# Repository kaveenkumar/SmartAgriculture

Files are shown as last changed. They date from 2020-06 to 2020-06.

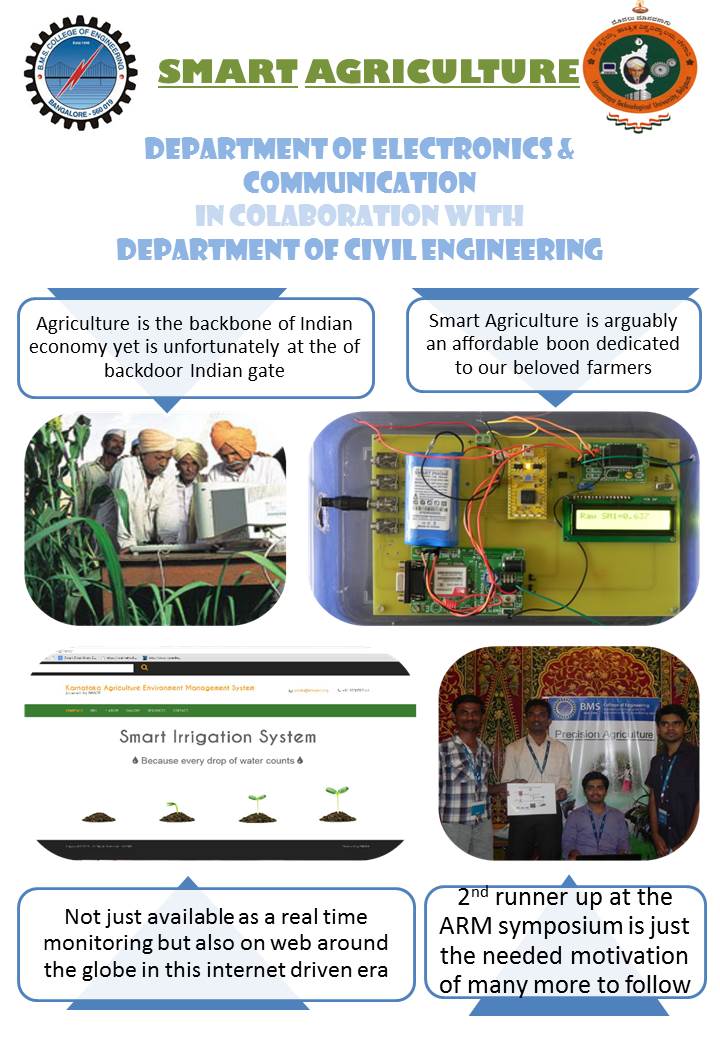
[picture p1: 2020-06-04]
Posters/SA Poster/Smart Agriculture poster.jpg

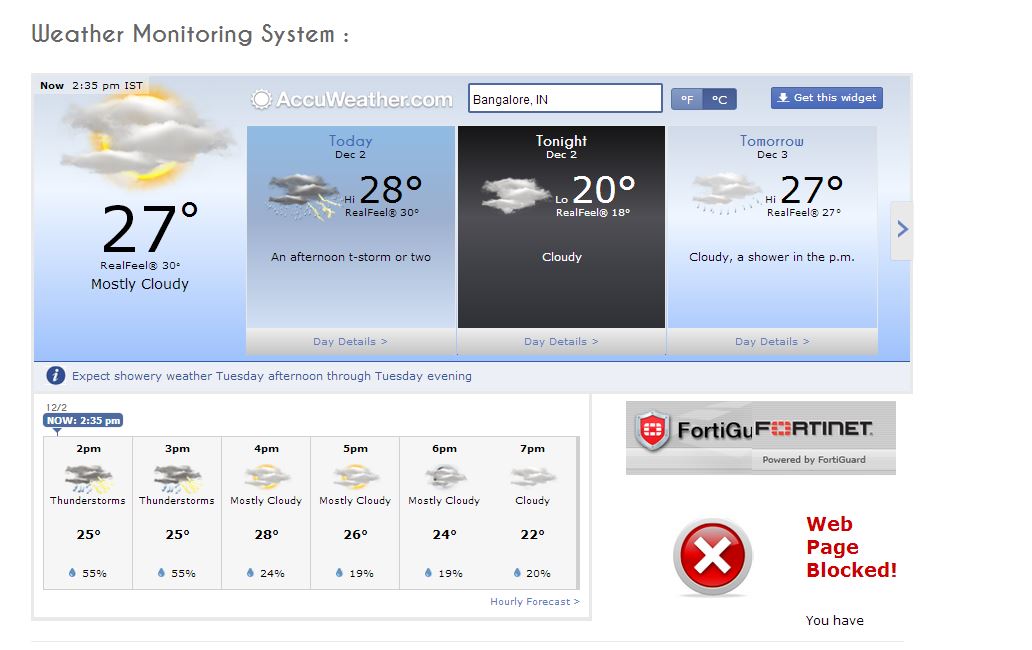
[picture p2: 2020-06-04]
Images/6.JPG

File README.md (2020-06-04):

# SmartAgriculture
Bachelor’s final year project, 2014.

## Control of waterflow to irrigation lands from a central system using wireless communication.
Currently deployed at the institute, BMS College of Engineering, Bangalore

### Reference
https://www.researchgate.net/project/Smart-Agriculture-13

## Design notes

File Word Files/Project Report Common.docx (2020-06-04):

B.M.S COLLEGE OF ENGINEERING

(Autonomous College under VTU)

Department of Electronics and Communication Engineering

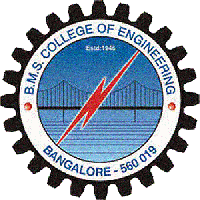
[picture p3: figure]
495086587logo%20bms

CERTIFICATE

This is to certify that the project entitled “PRECISION AGRICULTURE” is a bonafide work carried out by Hemantha Gowda C V (USN:1BM11EC406), Kaveen Kumar M K (USN:1BM11EC408), Nikhil D G (USN:1BM11EC415) and Prathap J (USN:1BM11EC417) in partial fulfillment for the award of Bachelor of Engineering degree by VTU Belgaum, during the academic year 2013-2014.

Harish V Mekali Dr.D .Seshachalam Dr.K.Mallikharjuna Babu

Assistant Prof., ECE, BMSCE HOD, ECE, BMSCE Principal, BMSCE

External Examination: Signature with date:

1.

2.

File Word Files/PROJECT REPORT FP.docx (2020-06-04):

PROJECT REPORT

ON

“PRECISION AGRICULTURE”

Submitted in partial fulfilment of the requirements for the award of degree of

BACHELOR OF ENGINEERING

IN

ELECTRONICS AND COMMUNICATION ENGINEERING

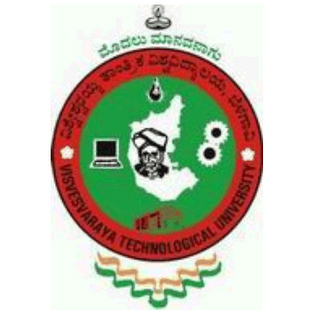
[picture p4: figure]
vtu_logo_gif

VISVESVARAYA TECHNOLOGICAL UNIVERSITY, BELGAUM

SUBMITTED BY:

HemanthaGowda C V 1BM11EC406

Kaveen Kumar M K 1BM11EC408

Nikhil D G 1BM11EC415

Prathap J 1BM11EC417

Under the Guidance of

Harish V Mekali

(Assistant Professor, ECE, BMSCE)

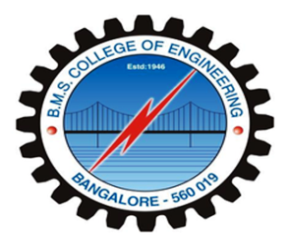
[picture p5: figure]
BMS LOGO

Department of Electronics and Communication Engineering

B.M.S COLLEGE OF ENGINEERING

(Autonomous College Affiliated to Visvesvaraya Technological University, Belgaum)

Bull Temple Road, Basavanagudi, Bangalore-560019

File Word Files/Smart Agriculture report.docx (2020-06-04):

PROJECT REPORT

ON

“SMART AGRICULTURE”

Submitted in partial fulfilment of the requirements for the award of degree of

BACHELOR OF ENGINEERING

IN

ELECTRONICS AND COMMUNICATION ENGINEERING

VISVESVARAYA TECHNOLOGICAL UNIVERSITY, BELGAUM

SUBMITTED BY:

Hemantha Gowda C V 1BM11EC406

Kaveen Kumar M K 1BM11EC408

Nikhil D G 1BM11EC415

Prathap J 1BM11EC417

Under the Guidance of

Harish V Mekali

(Assistant Professor, ECE, BMSCE)

Department of Electronics and Communication Engineering

B.M.S COLLEGE OF ENGINEERING

(Autonomous College Affiliated to Visvesvaraya Technological University, Belgaum)

Bull Temple Road, Basavanagudi, Bangalore-560019

B.M.S COLLEGE OF ENGINEERING

(Autonomous College under VTU)

Department of Electronics and Communication Engineering

CERTIFICATE

This is to certify that the project entitled “SMART AGRICULTURE” is a bonafide work carried out by Hemantha Gowda C V(USN:1BM11EC406), Kaveen Kumar M K (USN:1BM11EC408),Nikhil D G(USN:1BM11EC415) and Prathap J (USN:1BM11EC417) in partial fulfillment for the award of Bachelor of Engineering degree by VTU Belgaum, during the academic year 2013-2014.

Harish V Mekali Dr.D .Seshachalam Dr.K.Mallikharjuna Babu

Assistant Prof., ECE, BMSCE HOD, ECE, BMSCE Principal, BMSCE

External Examination: Signature with date:

1.

2.

This work is dedicated to all the farmers of the nation

ABSTRACT

Our planet is progressively marching towards a serious electric energy crisis, owing to an escalating desire of electric energy becoming greater than its supply. We have always failed to accept that the energy we make use of each day is restricted, yet taking it for granted. Coal, petroleum, electric power, even water has inadequate availability. Nevertheless, we have not taken sufficient precautions to handle a possible energy crisis. Another main concern has been the lifespan of guided media and its loopholes to intercept and eavesdrop.

Agricultural sector has maintained a dominant position on economy and as a natural supply for the country. Understanding the effects of heat and humidity, rain and erosion is the need of the day. Given the recent technological improvements the world has seen, failing to make use of it would be a sin on mankind. Here comes the need for a systematic hold on monitor of the data. As with the increase in technological innovations, so is the increase in required source power. An open minded effort would be to keep an eye on these available values from a remote location, interfacing a spot-on display, along with minimal power as possible.

ACKNOWLEDGEMENT

Any achievement, be it scholastic or otherwise does not depend solely on the individual efforts but on the guidance, encouragement and cooperation of intellectuals, elders and friends. A number of personalities, in their own capacities have helped us in carrying out this project work. We would like to take this opportunity to thank them all.

We express profound gratitude to respected principal Dr. K. Mallikharjuna Babu, BMS College of Engineering for providing a congenial environment to work in.

Our sincere gratitude to Dr. D. Seshachalam, Head of the Department, Electronics and Communication Engineering for encouraging and providing this opportunity to carry out the project in the department.

We would like to thank our guide Mr. Harish V. Mekali, Assistant Professor, Department of ECE who helped us in all the ways to carry out the project work. He stood beside and guided us in every step.

Our heartfelt thanks to Dr. K. R. Suresh, Professor, Dept. of Civil Engineering, for providing valuable information regarding agriculture and funding the complete project

Our special thanks to Dr. Sadanand Gulwadi, University Relation Manager, ARM, for providing the ARM MBED Cortex-M0 boards around which project has been built.

We will be incomplete, if we don't mention our heartfelt thanks to Mr. Ashrith, 5th Sem,CSE, BMSCEfor his expertise at Web Page development & the corresponding software parts.

We would like to share the joy completing the project to all the team members of NXP lab.

We thank all our professors for providing the basic knowledge without which this project wouldn't have been possible. Last but not the least we thank our family and friends, who made their valuable support compelled us to maintain a standard throughout our endeavour.

SPONSOR DETAILS

We are very much thankful to Visvesvaraya Technological University for funding the entire project.

TABLE OF CONTENTS

CHAPTER TOPICPAGENO

- ABSTRACT 4

- ACKNOWLEDGEMENT 5

- LITERATURE SURVEY 8

1 INTRODUCTION 9

2 PROJECT FLOW 13

3 TESTING 26

4 CONCLUSION 36

5 FUTURE WORK 37

- BIBLIOGRAPHY 38

- RECOGNITION 40

- ANNEXURE 41

Data acquisition model

SIM900A

Display

Battery

optocoupler

Relay

Soil temperature sensor

Battery level indicator

LITERATURE SURVEY

1. ‘Automated Irrigation System Using a Wireless Sensor Network and GPRS Module (http://ieeexplore.ieee.org/xpl/articleDetails.jsp?tp=&arnumber=6582678)’, By - Gutierrez, J. (http://ieeexplore.ieee.org/search/searchresult.jsp?searchWithin=p_Authors:.QT.Gutierrez,%20J..QT.&newsearch=true), Villa-Medina, J.F. (http://ieeexplore.ieee.org/search/searchresult.jsp?newsearch=true), Nieto-Garibay, A. (http://ieeexplore.ieee.org/search/searchresult.jsp?newsearch=true), Porta-Gandara M.A. (http://ieeexplore.ieee.org/search/searchresult.jsp?newsearch=true)

- Knowledge on the design mainly consisting of wireless sensor network and wireless information unit that’s based on Zigbee technology and is realized using GPRS module and concentrated on low power consumption.
- Knowledge on achieving low power consumption using PIC.
- Knowledge on sensor network powered by solar panel with rechargeable battery that works for a longer time.
- Knowledge on UART interfaces with microcontroller that can accept the data with a speed of 115.2kbps from GPRS module.
2. ‘Smart Orchid Soil Moisture Monitoring System Based on Wireless Communication Technology’By- Ye Na & Liu Junfeng.
- Insight on the system cored with a Low-Power Microprocessor ‘MSP430f149 MCU’ which employs smaller radiations to the environment and human body.
- Insight on achieving a wide range of influence on soil moisture and intelligent control of data in a fixed memory.
- Insight on achieving a 24hr uninterrupted monitoring.
- Insight on serial non-volatile data memory chip for storage and display device, that is based on I2C bus, in turn using multifunctional memory chip of the ferroelectric technology which contains RTC.
3. ‘The optimizing design and application of a new wireless Low-power universal data acquisition system’ By- Yan-fei ai1, yu-jie hao1, jian-ping li1.
- Perspective on breakthrough of traditional network communication by employing multi interface design consisting of Zigbee terminal, Zigbee router, Zigbee coordinator.
- Perspective on similar interface device connectivity with TI's chip TUSB3410 & integrated CS8900 Ethernet chip to support Ethernet interface to realize Ethernet communications; realizing serial port connectivity with PC.
- Perspective on optimization of data communication by avoiding data conflicts using hexagon method.

CHAPTER I

INTRODUCTION

Agriculture uses 85% of available fresh water resources worldwide and this percentage will continue to be dominant in water consumption because of population growth and increased food demand. There is an urgent need to create strategies based on science and technology for sustainable use of water, including technical, agronomic, managerial and institutional improvements. For every 18 months the demand for electric based requirements increases two-fold.

The proposed project has been our brain child on such a low power DAS. We have proudly maintained a check on power requirement the without degrading the quality of it. This low power data acquisition system can be used in farm fields for acquiring the values of temperature and humidity using sensors.

### 1.1 WEATHER MONITORING SYSTEM

We would like to begin by introducing our head start, another similar important project ‘WEATHER MONITORING SYSTEM’ by a fellow college mate Mr. Nithin whose work is based on monitoring the various factors of weather. We happily like to extend that this project has been successfully completed with the required outcomes matching his expectations.

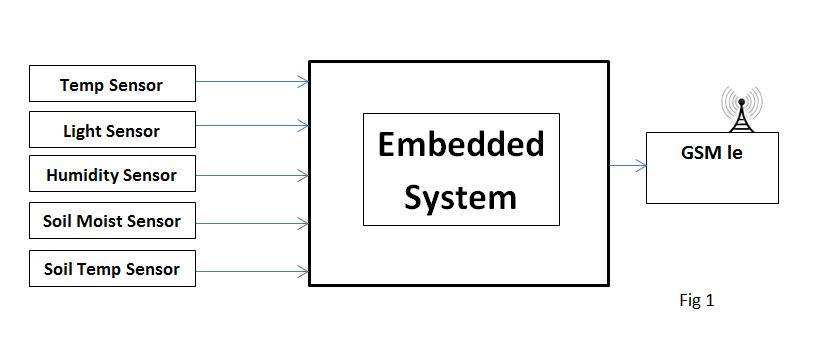
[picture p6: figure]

Fig 1.1(a): Depicts the transmitter part of the embedded system where the sensors read the values and sends them to a mobile phone in the form of SMS through GSM Module.

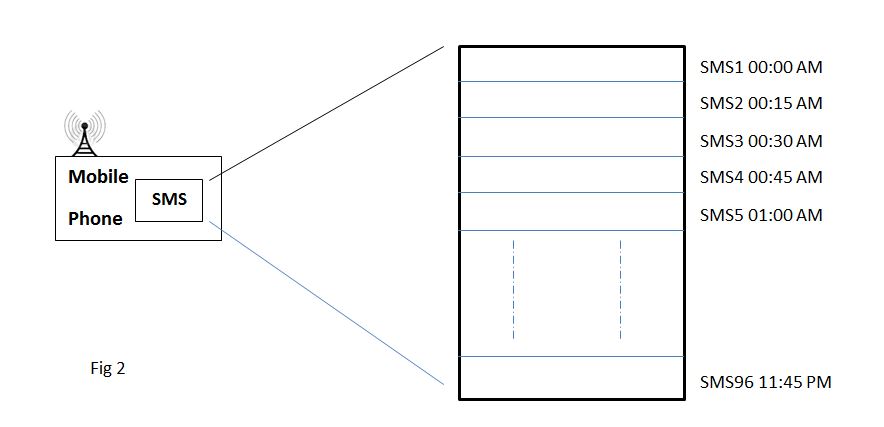
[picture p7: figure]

Fig 1.1(b):Receiver part of the embedded system where messages received for every 15 mins will be stacked in the mobile storage.

SMS Format will be as given below.

Temp:29⁰C SM:25% ST:18⁰C Lum:100lux RH:20%

Fig 1.1(c):Output working where get the graph of the corresponding parameter as shown above.

The aim of the project is to get the graph of the required parameter values.

## 1.2 Proposed Problem

But the qualitative output comes at a cost of the power required. The power consumption is relevantly high to the expected working. In a single statement the problem can be pointed as

“No ‘Data Acquisition System’ at a remote area is perfect unless it works at a considerably low power & extended battery life at least for a duration of year and more.”

## 1.3Diagnosed solution

Our innovation “Smart Agriculture” can be called as a successor of the above mentioned ‘WMS’.

As a sensible world resident, we begin by investigating alternative power solutions and advancement in technology, forexample solar, wind electric energy and LDOs respectively. Utilizing these alternative energy solutionsin as a whole is comparatively realistic and cheap to modern day units. Technical solutions, previously accomplished using Analog circuitry, have been converted into data acquisition systems that translate Analog input signals into digital information and process the binary data. With a few additional ideas to decrease the power consumption by employing solar cells and the improved features provided by ARM such as ‘Sleep Mode’ we lend a heavy help.

## 1.4 Implementation Model

Microcontroller: ARM Cortex M0 works as the heart of the project. It controls the output peripherals depending on the input sensor thresholds.

Sensors: Variety of sensors are used to detect the physical conditions of the environment such as moisture, temperature, humidity etc.

LCD Display: LCD 16x2 Display employed displays the various parameters of the sensors.

Solar Panel– Battery: The Solar panel helps in providing power by acquiring the energy from the Sun’s rays. This in-turn is fed to the battery employed for storage and future uses.

GSM: A GSM module is employed in the project such that the read values are not only displayed but also available online through the internet connection.

## 1.5 Block Diagram

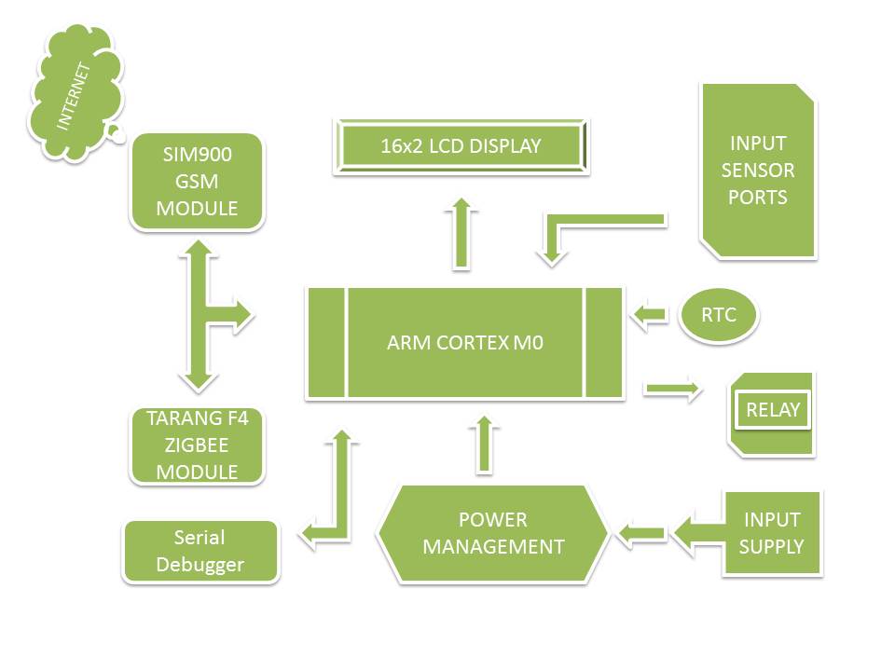
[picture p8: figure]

Fig. 1.5 Conceptual block diagram of the model

CHAPTER - II

PROJECT FLOW

## 2.1 COMPONENTSUSED

- ARM CORTEX MICROCONTROLLER
- SOIL MOISTURE SENSOR
- LCD DISPLAY
- OPTO-COUPLER
- RELAY
- ZIGBEE MODULE
- GSM MODULE
- REAL TIME CLOCK
- USB
- SOLAR PANEL

## 2.2 HARDWARES:

## 2.2.1 ARM CORTEX M0 LPC11U24:

Fig. 2.2.1ARM Cortex-M0

## 2.2.2 General description

- The LPC11U2x are an ARM Cortex-M0 based, low-cost 32-bit MCU family, designed for 8/16-bit microcontroller applications, offering performance, low power, simple instruction set and memory addressing together with reduced code size compared to existing 8/16-bit architectures.
- The LPC11U2x operate at CPU frequencies of up to 50 MHz
- Equipped with a highly flexible and configurable full -Speed USB 2.0 device controller, the LPC11U2x brings unparalleled design flexibility and seamless integration to today’s demanding connectivity solutions.
- The peripheral complement of the LPC11U2x includes up to 32 kB of flash memory, up to 10 kB of SRAM data memory and 4 kB EEPROM, one Fast -mode Plus I²C-bus interface, one RS-485/EIA-485 USART with support for synchronous mode and smart card interface, two SSP interfaces, four general- purpose counter/timers, a 10-bit ADC (Analogy-to-Digital Converter), and up to 54 general-purpose I/O pins.

## 2.4 LCD 16x2 DISPLAY

Fig. 2.4 LCD 16x2 Display

LCD (Liquid Crystal Display): A 16x2 LCD display is very basic module and is very commonly used in various devices and circuits. These modules are preferred over seven segments (http://www.engineersgarage.com/content/seven-segment-display) and other multi segment LED (http://www.engineersgarage.com/content/led)s. The reasons being: LCDs are economical; easily programmable; have no limitation of displaying special & even custom characters (http://www.engineersgarage.com/microcontroller/8051projects/create-custom-characters-LCD-AT89C51) (unlike in seven segments) animations (http://www.engineersgarage.com/microcontroller/8051projects/display-custom-animations-LCD-AT89C51) andso on.

A 16x2 LCD means it can display 16 characters per line and there are 2 such lines. In this LCD each character is displayed in 5x7 pixel matrix. This LCD has two registers, namely, Command and Data.

The command register stores the command instructions given to the LCD. A command is an instruction given to LCD to do a predefined task like initializing it, clearing its screen, setting the cursor position, controlling display etc. The data register stores the data to be displayed on the LCD. The data is the ASCII value of the character to be displayed on the LCD. Click to learn more about internal structure of a LCD (http://www.engineersgarage.com/insight/how-lcd-works).

## 2.4.1 Pin Description:

Pin No | Function | Name
1 | Ground (0V) | Ground
2 | Supply voltage; 5V (4.7V – 5.3V) | Vcc
3 | Contrast adjustment; through a variable resistor | VEE
4 | Selects command register when low; and data register when high | Register Select
5 | Low to write to the register; High to read from the register | Read/write
6 | Sends data to data pins when a high to low pulse is given | Enable
7 | 8-bit data pins | DB0
8 | | DB1
9 | | DB2
10 | | DB3
11 | | DB4
12 | | DB5
13 | | DB6
14 | | DB7
15 | Backlight VCC (5V) | Led+
16 | Backlight Ground (0V) | Led-

Table 2.4.1Pin description of LCD 16x2 Display

## 2.5 OPTO-COUPLER:

Fig. 2.5(a) Opto-Coupler IC

The HCPL-817 contains a light emitting diode optically coupled to a phototransistor. It is packaged in a 4-pin DIP package and available in wide-lead spacing option and lead bend SMD option. Input-output isolation voltage is 5000 Vrms. Response time, tr, is typically 4 µs and minimum CTR is 50% at input current of 5 mA.

`

Fig. 2.5(b) Internal connection and schematic of Opto-Coupler IC PC817

TARANG F4 ZIGBEE MODULE:

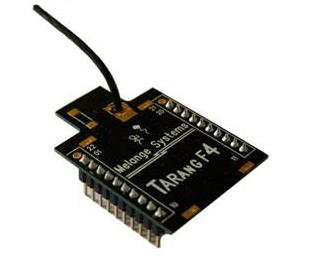
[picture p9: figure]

MELANGE TANRANG F4 ZIGBEE MODULE

ZigBee is a low-cost, low-power, wireless mesh network standard. The low cost allows the technology to be widely deployed in wireless control and monitoring applications. Low power usage allows longer life with smaller batteries. Mesh networking provides high reliability and more extensive range. ZigBee chip vendors typically sell integrated radios.

The ZigBee network layer natively supports both star and tree typical networks, and generic mesh networks. Every network must have one coordinator device, tasked with its creation, the control of its parameters and basic maintenance. Within star networks, the coordinator must be the central node. Both trees and meshes allows the use of ZigBee routers to extend communication at the network level.

## Features and Benefits:

- Point to point, point to multi point, Mesh and peer-to-peer topologies on proprietary stack.
- Direct Sequence Spread Spectrum technology.
- Each direct sequence channel has 64K unique network addresses.
- Transmit Power: 0 dBs
- RF data rate: 250 kbps.
- Acknowledgement mode communication with retries.
- Power saving modes.
- Source / destination addressing.
- Unicast and broadcast communication.
- Analog to digital conversion and digital I/O line support.
- Default configuration for ready to use.

## Specifications:

# Power

Supply Voltage | 3.3 to 3.6V
Transmit Current | 45mA
Idle/Receive Current | 50mA
Power-down Current | <10 µA

# General

Rating Frequency | ISM 2.4 - 2.4835 GHz
Maximum Transmit Power Output | 1mW (+0 dBm)
RF Data Rate | 250 kbps
Receiver Sensitivity | -92 dBm
Serial Interface Data Rate | Up to 115200 baud
Operating Temperature | -40 to 85 °C
Antenna Options | Chip Antenna, Wire Antenna
Antenna Connector | MMCX

# Network

Supported Network Topologies | Peer-to-peer, point to multipoint & Mesh
Number Of Channels | 16 direct sequence channels
Addressing Options | PAN ID, Channel and addresses

# Mechanical

Dimensions | 37mm x 26mm.
Interface Connector | 20 pin receptacles, 2.00mm pitch.

A Wireless Distributed Network (WSN) has distributed autonomous (http://en.wikipedia.org/wiki/Autonomous) sensors (http://en.wikipedia.org/wiki/Sensor) to monitor physical or environmental conditions, such as temperature, sound, pressure (http://en.wikipedia.org/wiki/Pressure), etc. and to cooperatively pass their data through the network to a main location. The WSN is built of "nodes" – from a few to several hundreds or even thousands, where each node is connected to one (or sometimes several) sensors.

ZigBee based wireless sensor networks have tremendous usage potential, because they are much more flexible in both installation and running operation mode than conventional wired networks. ZigBee wireless networks are adaptive and self-healing, that means these networks can withstand even hostile changes in the environment, like devices leaving the network due to hardware malfunctions or electromagnetic interferences. The ZigBee specification puts very much emphasis on battery power conservation all the layers (physical, Media Access Control (MAC), network and application) from the ground up (IEEE 802.15.4) support this most important goal. The standard specifies that a ZigBee End Device (ZED) must be able to operate at a minimum for 2 years on a single battery cell. [1] The transmission is low data rate, that means that while the maximum theoretical throughput between two devices can be up to around 250 kbps.

## 2.6 SIM900 GSM MODULE:

You need only two wires (TX, RX) except Power supply to interface with microcontroller / Arduino. The built in Power supply allows you to connect wide range unregulated power supply. Using this modem, you can send SMS, data and read SMS through simple AT command.

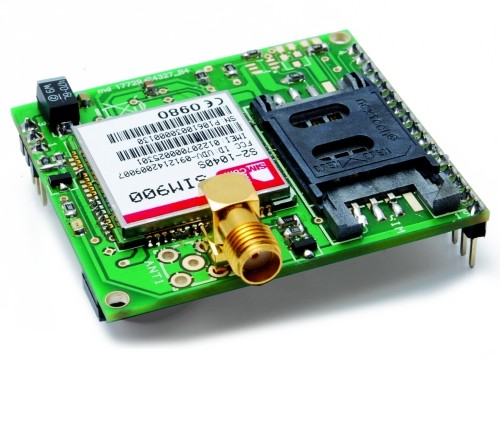
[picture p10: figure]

Fig. 2.6 SIM900 GSM MODULE

This is a complete Quad-band GSM/GPRS module in a SMT type and designed with a very powerful single-chip processor integrating AMR926EJ-S core, allowing you to benefit from small dimensions and cost-effective solutions.

Featuring an industry-standard interface, the SIM900 delivers GSM/GPRS 850/900/1800/1900MHz performance for voice, SMS, Data, and Fax in a small form factor and with low power consumption. With a tiny configuration of 24mm x 24mm x 3 mm, SIM900 can fit almost all the space requirements in your M2M applications, especially for slim and compact demands of design.

## 2.7 DC-12V RELAY:

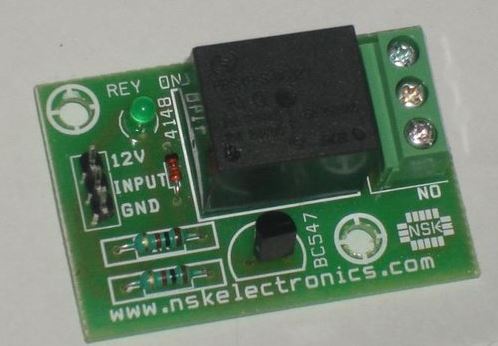
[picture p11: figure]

Fig. 2.7 Relay

A relay is an electrical switch that uses an electromagnet to move the switch from the off to on position instead of a person moving the switch. It takes a relatively small amount of power to turn on a relay but the relay can control something that draws much more power.

## 2.7.1 OPERATION OF RELAY:

Relays (and switches) come in different configurations. The most common are shown to the right. Single Pole Single Throw (SPST) is the simplest with only two contacts. Single Pole Double Throw (SPDT) has three contacts. The contacts are usually labelled Common (COM), Normally Open (NO), and Normally Closed (NC). The Normally Closed contact will be connected to the Common contact when no power is applied to the coil. The Normally Open contact will be open (i.e. not connected) when no power is applied to the coil. When the coil is energized the Common is connected to the Normally Open contact and the Normally Closed contact is left floating. The Double Pole versions are the same as the Single Pole version except there are two switches that open and close together. Select a relay with contacts that can handle the voltage and current requirements of the load. Keep in mind that some loads (such as motors) draw much more current when first turned on than they do at steady state. Select a relay with a coil voltage and current that you can control easily. Ex: If you want to turn on the AC unit with a 12VDC power supply get a 12VDC coil. Note: Coils will be rated for either AC or DC.

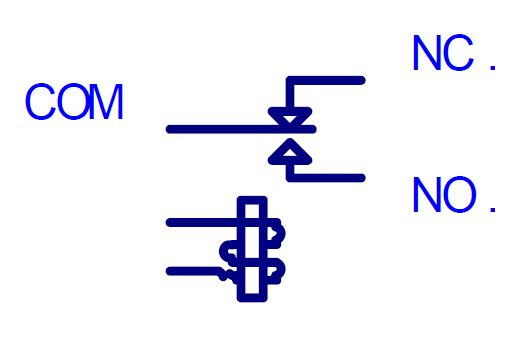
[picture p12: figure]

Fig. 2.7.1 Relay Operation

## 2.7.2 The primary functions of a relay are:

- The galvanic separation of the primary or actuating circuit and the load circuits
- Single input/multiple output capability
- Separation of different load circuits for multi-pole relays
- Separation of AC and DC circuits
- Interface between electronic and power circuits
- Multiple switching functions, e.g. delay, signal conditioning
- Amplifier function.

## 2.7.3 Applications of Relay:

Typical applications for relays include laboratory instruments, telecommunication systems, computer interfaces, domestic appliances, air conditioning and heating, automotive electrics, traffic control, lighting control, building control, electric power control, business machines, control of motors and solenoids, tooling machines, production and test equipment.

## 2.8 SENSORS:

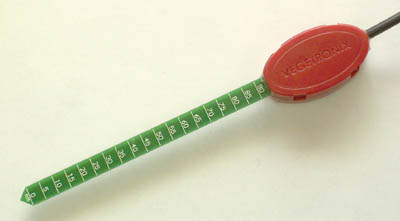
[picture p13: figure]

Fig 2.8VH400 Moisture sensor

## 2.8.1 Moisture Sensor:

High frequency VH400 series soil moisture sensor probes enable precise low cost monitoring of soil water content. Because our probe measures the dielectric constant of the soil using transmission line techniques, it is insensitive to water salinity, and will not corrode over time as does conductivity based probes. Our probes are small, rugged, and low power.

Compared to other low cost sensor such as gypsum block sensors, our probes offer a rapid response time. They can be inserted and take an accurate reading in under 1 second.

The VH400 operates at a much higher frequency and it is much more sensitive at higher VWC levels, and its curves are more linear.

Probes come standard with a 2 meter cable.

## 2.8.2 Soil Moisture Sensor Probe Applications:

- Irrigation and sprinkler systems.
- Moisture monitoring of bulk foods.
- Rain and weather monitoring.
- Environmental monitoring.
- Water conservation applications.
- Fluid level measurements.

## 2.8.3 Soil Moisture Sensor Probe Features:

- Extreme low cost with volume pricing.
- Not conductivity based.
- Insensitive to salinity.
- Probe does not corrode over time.
- Rugged design for long term use.
- Small size.
- Consumes less than 600uA for very low power operation.
- Precise measurement.
- Measures volumetric water content (VWC) or gravimetric water content (GWC).
- Patent pending technology.
- Output Voltage is proportional to moisture level.
- Wide supply voltage range.
- Can be buried and is water proof.
- Probe is long and slender for wider use, including smaller potted plants.

REAL TIME CLOCK:

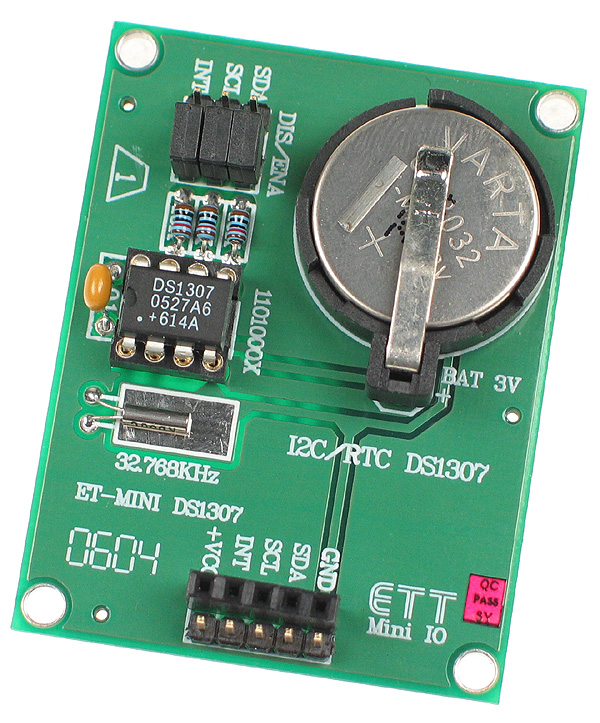
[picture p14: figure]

REAL TIME CLOCK

A real-time clock (RTC) is a computer (http://en.wikipedia.org/wiki/Computer) clock (http://en.wikipedia.org/wiki/Clock) (most often in the form of an integrated circuit (http://en.wikipedia.org/wiki/Integrated_circuit)) thatkeeps track of the current time (http://en.wikipedia.org/wiki/Time). Although the term often refers to the devices in personal computers (http://en.wikipedia.org/wiki/Personal_computer), servers (http://en.wikipedia.org/wiki/Server_(computing)) and embedded systems (http://en.wikipedia.org/wiki/Embedded_system), RTCs are present in almost any electronic device which needs to keep accurate time.

RTCs often have an alternate source of power, so they can continue to keep time while the primary source of power is off or unavailable. This alternate source of power is normally a lithium battery (http://en.wikipedia.org/wiki/Lithium_battery) in older systems, but some newer systems use a supercapacitor (http://en.wikipedia.org/wiki/Supercapacitor)because they are rechargeable and can be soldered (http://en.wikipedia.org/wiki/Soldering). The alternate power source can also supply power to battery backed RAM (http://en.wikipedia.org/wiki/Nonvolatile_BIOS_memory).

Most RTCs use a crystal oscillator (http://en.wikipedia.org/wiki/Crystal_oscillator) but some use the power line frequency (http://en.wikipedia.org/wiki/Utility_frequency).In many cases the oscillator's frequency is 32.768 kHz. This is the same frequency used inquartz clocks and watches (http://en.wikipedia.org/wiki/Quartz_clock), and for the same reasons, namely that the frequency is exactly 2¹⁵ cycles per second, which is a convenient rate to use with simple binary counter circuits.

Purpose:

- Low power consumption(important when running from alternate power)
- Frees the main system for time-critical tasks
- Sometimes more accurate than other methods

USB FLASH DRIVE CONNECTIVITY:

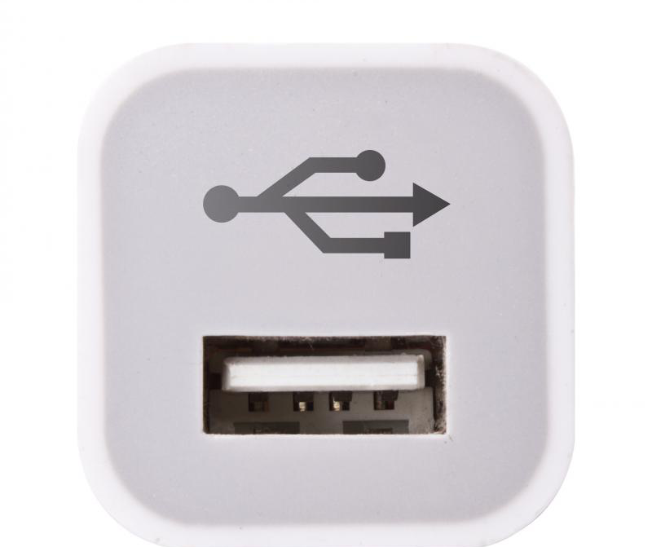
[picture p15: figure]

USB FEMALE PORT USB FLASH DRIVE

A USB flash drive is a data storage device (http://en.wikipedia.org/wiki/Data_storage_device) that includes flash memory (http://en.wikipedia.org/wiki/Flash_memory) with an integrated Universal Serial Bus (http://en.wikipedia.org/wiki/Universal_Serial_Bus) (USB) interface. USB flash drives are typically removable and rewritable, and physically much smaller than an optical disc (http://en.wikipedia.org/wiki/Optical_disc). Most weigh less than 30 grams (1.1 oz). Storage capacities as large as 2 TB are planned, with steady improvements in size and price per capacity expected.[4] (http://en.wikipedia.org/wiki/USB_flash_drive) Some allow up to 100,000 write/erase cycles, depending on the exact type of memory chip used, and a 10-year shelf storage time (http://en.wikipedia.org/wiki/Digital_permanence).They are smaller, faster, have thousands of times more capacity, and are more durable and reliable because they have nomoving parts (http://en.wikipedia.org/wiki/Moving_parts). Additionally, they are immune to magnetic interference (unlike floppy disks), and unharmed by surface scratches (unlike CDs). USB flash drives use the USB mass storage (http://en.wikipedia.org/wiki/USB_mass_storage_device_class) standard, supported natively by modern operating systems (http://en.wikipedia.org/wiki/Operating_system) such as Linux (http://en.wikipedia.org/wiki/Linux), OS X (http://en.wikipedia.org/wiki/OS_X), Windows (http://en.wikipedia.org/wiki/Microsoft_Windows), and other Unix-like (http://en.wikipedia.org/wiki/Unix-like) systems, as well as many BIOS (http://en.wikipedia.org/wiki/BIOS) boot ROMs. USB drives with USB 2.0 support can store more data and transfer faster than much larger optical disc drives (http://en.wikipedia.org/wiki/Optical_disc_drive).

A flash drive consists of a small printed circuit board (http://en.wikipedia.org/wiki/Printed_circuit_board) carrying the circuit elements and a USB connector, insulated electrically and protected inside a plastic, metal, or rubberized case which can be carried in a pocket or on a key chain, for example. The USB connector may be protected by a removable cap or by retracting into the body of the drive, although it is not likely to be damaged if unprotected. Most flash drives use a standard type-A USB connection (http://en.wikipedia.org/wiki/Universal_Serial_Bus) allowing connection with a port on a personal computer, but drives for other interfaces (http://en.wikipedia.org/wiki/USB_flash_drive) also exist. USB flash drives draw power from the computer via the USB connection.

Essential Components in an USB:

- Standard-A USB plug – provides a physical interface to the host computer.
- USB mass storage controller – a small microcontroller (http://en.wikipedia.org/wiki/Microcontroller) with a small amount of on-chip ROM (http://en.wikipedia.org/wiki/Read-only_memory) and RAM (http://en.wikipedia.org/wiki/Random_Access_Memory).
- NAND flash (http://en.wikipedia.org/wiki/NAND_flash) memory chip(s) – stores data (NAND flash is typically also used in digital cameras (http://en.wikipedia.org/wiki/Digital_camera)).
- Crystal oscillator (http://en.wikipedia.org/wiki/Crystal_oscillator) – produces the device's main 12 MHz clock signal (http://en.wikipedia.org/wiki/Clock_signal) and controls the device's data output through a phase-locked loop (http://en.wikipedia.org/wiki/Phase-locked_loop).
- Cover - typically made of plastic or metal - to protect the electronics against mechanical stress and even possible short circuits

SOLAR ENERGY HARVESTING:

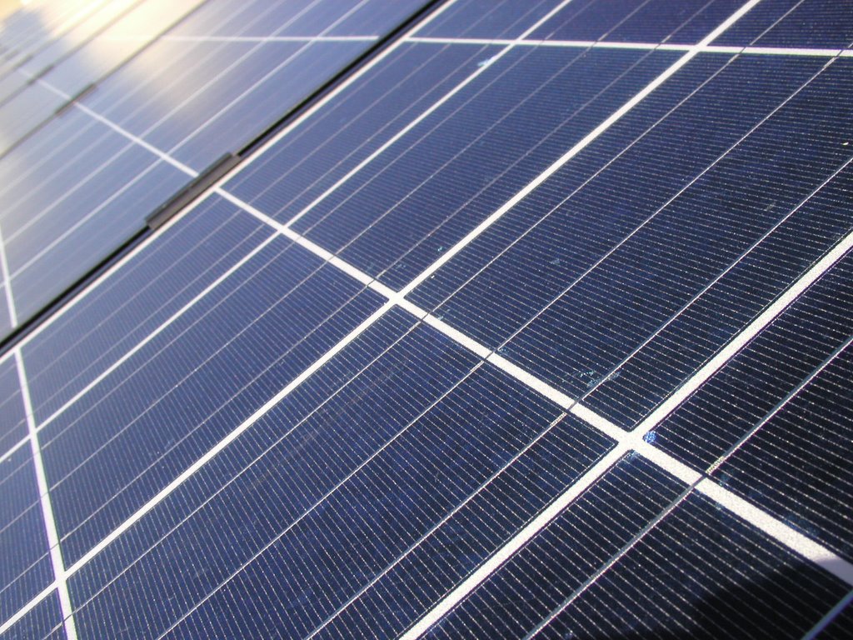
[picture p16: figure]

SOLAR PANEL

Solar energy, radiant light (http://en.wikipedia.org/wiki/Light) and heat (http://en.wikipedia.org/wiki/Heat) from the sun (http://en.wikipedia.org/wiki/Sun), is harnessed using a range of ever-evolving technologies such as solar heating (http://en.wikipedia.org/wiki/Solar_heating), solar photovoltaics (http://en.wikipedia.org/wiki/Solar_photovoltaics), solar thermal electricity (http://en.wikipedia.org/wiki/Solar_thermal_electricity), solar architecture (http://en.wikipedia.org/wiki/Solar_architecture) and artificial photosynthesis (http://en.wikipedia.org/wiki/Artificial_photosynthesis).

Solar technologies are broadly characterized as either passive solar (http://en.wikipedia.org/wiki/Passive_solar) or active solar (http://en.wikipedia.org/wiki/Active_solar) depending on the way they capture, convert and distribute solar energy. Active solar techniques include the use of photovoltaic panels and solar thermal (http://en.wikipedia.org/wiki/Solar_thermal_energy) collectors to harness the energy. Passive solar techniques include orienting a building to the Sun, selecting materials with favorablethermal mass (http://en.wikipedia.org/wiki/Thermal_mass) or light dispersing properties, and designing spaces that naturally circulate air (http://en.wikipedia.org/wiki/Ventilation_(architecture)).

The Earth receives 174 petawatts (http://en.wikipedia.org/wiki/Orders_of_magnitude_(power)) (PW) of incoming solar radiation (insolation (http://en.wikipedia.org/wiki/Insolation)) at the upper atmosphere (http://en.wikipedia.org/wiki/Earth%27s_atmosphere). Approximately 30% is reflected back to space while the rest is absorbed by clouds, oceans and land masses. The spectrum (http://en.wikipedia.org/wiki/Electromagnetic_spectrum) of solar light at the Earth's surface is mostly spread across the visible (http://en.wikipedia.org/wiki/Visible_light) and near-infrared (http://en.wikipedia.org/wiki/Near-infrared) ranges with a small part in the near-ultraviolet (http://en.wikipedia.org/wiki/Near-ultraviolet).Solar energy can be harnessed at different levels around the world, mostly depending on distance from the equator.

Yearly Solar fluxes & Human Energy Consumption
Solar | 3,850,000 EJ (http://en.wikipedia.org/wiki/Joule)[8] (http://en.wikipedia.org/wiki/Solar_energy)
Wind | 2,250 EJ[9] (http://en.wikipedia.org/wiki/Solar_energy)
Biomass potential | 100–300 EJ[10] (http://en.wikipedia.org/wiki/Solar_energy)
Primary energy use (2010) | 539 EJ[11] (http://en.wikipedia.org/wiki/Solar_energy)
Electricity (2010) | 66.5 EJ[12] (http://en.wikipedia.org/wiki/Solar_energy)

The project employs the benefits of solar energy harvesting once the input supply specifications are finalized. Using solar energy optimizes the circuit functions further more since the input supply power is minized as far as possible. Also this brings a certain value to the project.

Chapter III

TESTING

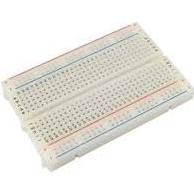
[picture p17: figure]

Fig 3.0 General representation of a Bread-Board

We initiated our idea on a General Bread-Board at the beginning. Our academics helped us to understand the basic model of a bread-board such that the connections upon it can be carried on with ease. Understanding of the internal connections is an important aspect with respect to the connections made upon it.

The overall project was carried forward by mounting the corresponding components on the Bread-Board as per the schematic.

3.1ARM CORTEX M0:

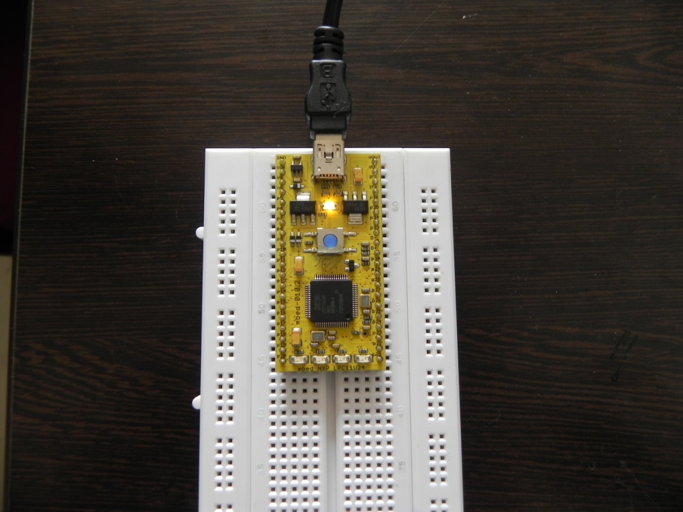
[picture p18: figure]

Fig 3.1 An ARM IC on a bread board

ARM Cortex was the utmost main component that we wished to test first by embedding it on the bread-board and through the interfacing of USB connector. It was tested by using our knowledge of the online compiler.

The purpose to use ARM Cortex- M0 is because of the fact that it is the lowest power consuming IC available from the family of ARM Controllers.

## 3.2 LCD DISPLAY:

Fig. 3.2 LCD 16x2 Display

The next step of our testing was occupied by the output device ‘LCD 16x2 Display’. We found it more important to display our outcomes through a device that can be more of an understanding to the outward world.

We even went to the extent of displaying our names quite naively.

## 3.3 Opto-coupler and Relay:

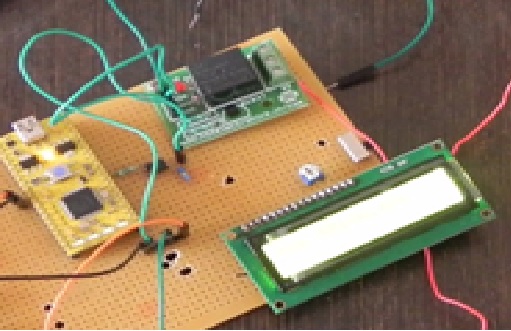
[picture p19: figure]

Fig 3.3 Connection of Opto-coupler and relay

We followed the interfacing cycle next by an opto-coupler. We followed it up with a relay to drive the solenoid valve. The main reason for using this opto-coupler was to provide isolation between the relay and the controller on one side. Also when the solenoid valve turns on it produces a back-emf which may turn out to be harmful to the controller. So in order to provide this very required isolation we employed the opto-coupler.

## 3.4Sensors:

Our need was fed by the values from the sensors that we employed. The moisture sensor was used to sense the moisture level of the soil which was inturn fed to the controller. We set a calibrating threshold as per our required level. The programming was such that when the sensor value exceeded the threshold the controller provided the control signal to turn off the solenoid valve.

## 3.5 Final Working Model:

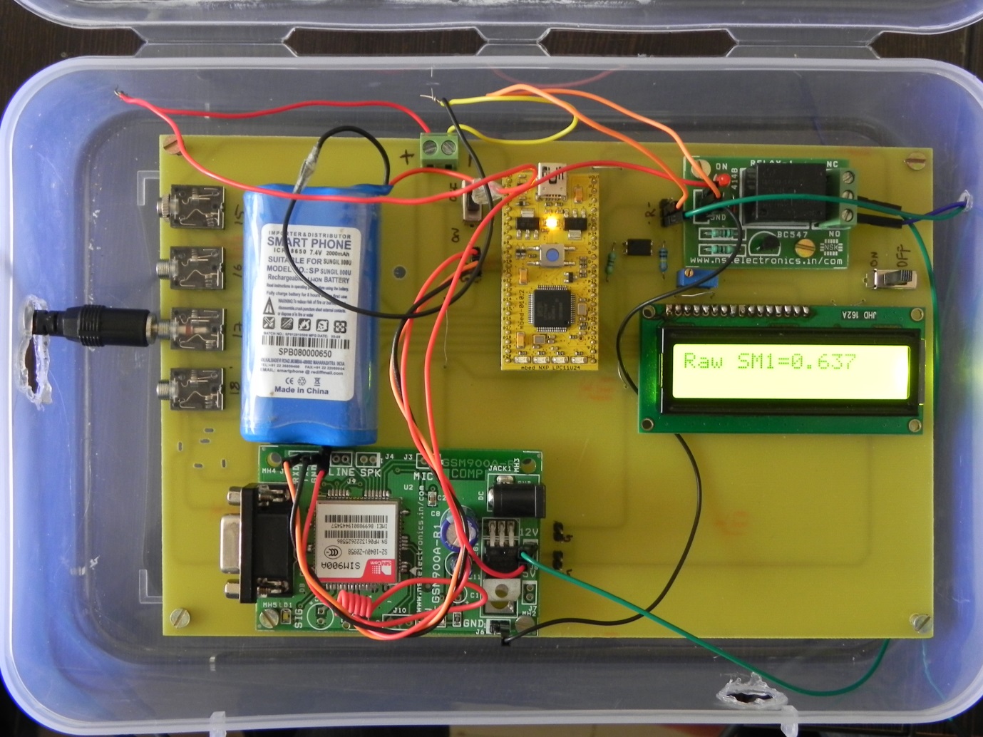
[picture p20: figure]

Fig 3.5 Final Working module on a PCB

## 3.6SOFTWARES:

1. System Software

Sl.No | Components | Reason for selection | Approx. cost
1. | Windows XP/7 OS | Experienced usage | -

2. Programming/Coding software

Sl.No | Components | Reason for selection | Approx. cost
1 | Mbed online compiler | C++ coding for ARM MBED board | -
2 | PHP Programming language | Basic web-page language | -

3. Application Software

Sl.No | Components | Reason for selection | Approx. cost
1. | Eagle layout editor 6.5.0 | PCB design | -
2 | HyperTerminal | Interfacing external modules to computer(PC/Laptop) | -

Fig 3.5 Tables of software used

## 3.7Software Layout:

On the other hand simultaneously we developed a model of the project on the PC as a soft format using ‘Eagle 6.5.0’. Though none of us was an expert on the field we managed to learn it and create a schematic and board layout.

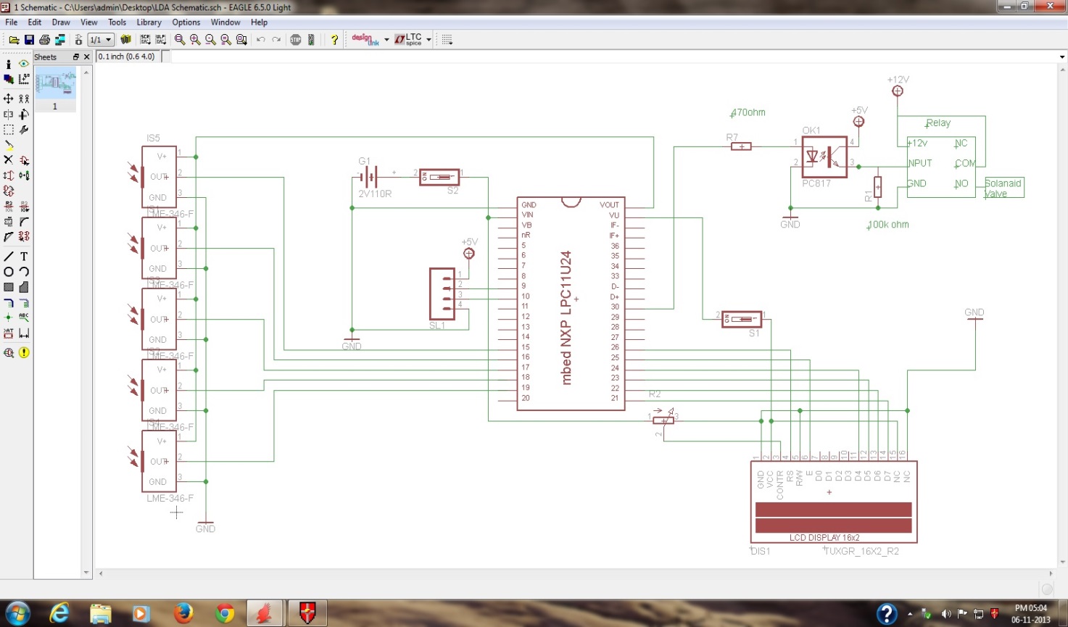
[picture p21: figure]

Fig. 3.7(a) FRONT VIEW OF PCB LAYOUT

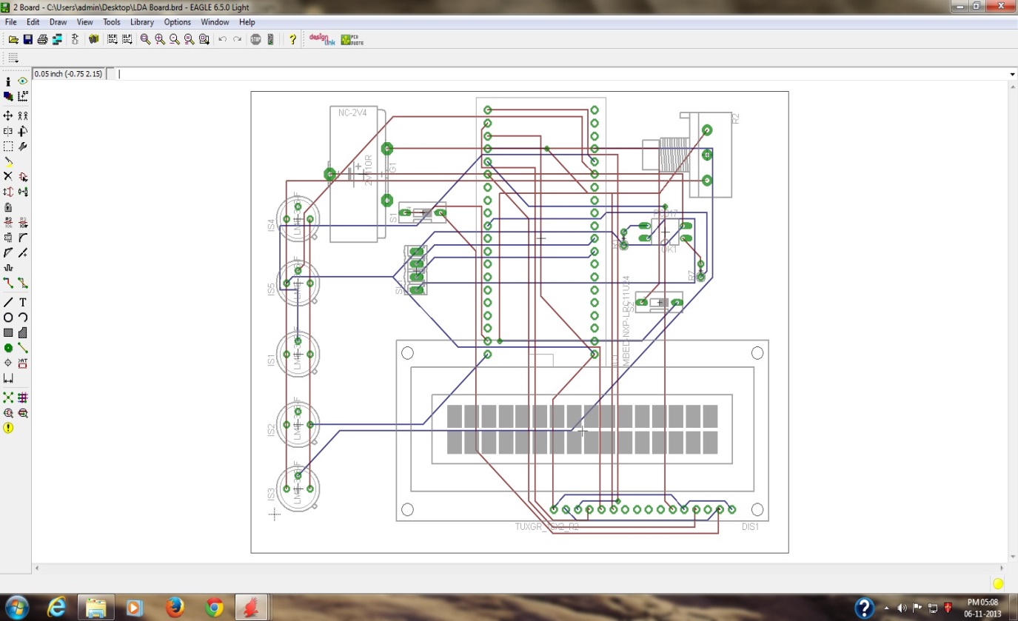
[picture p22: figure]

Fig 3.7(b)REAR VIEW

## 3.8 REMOTE DATA ACQUISITION:

### We provide an alternate method of interfacing the output not just with a display but also uploading the parameters to the internet through a GSM Module. Any user in need of knowing the information can log-in with his identity & a distinct secure password and can obtain it.

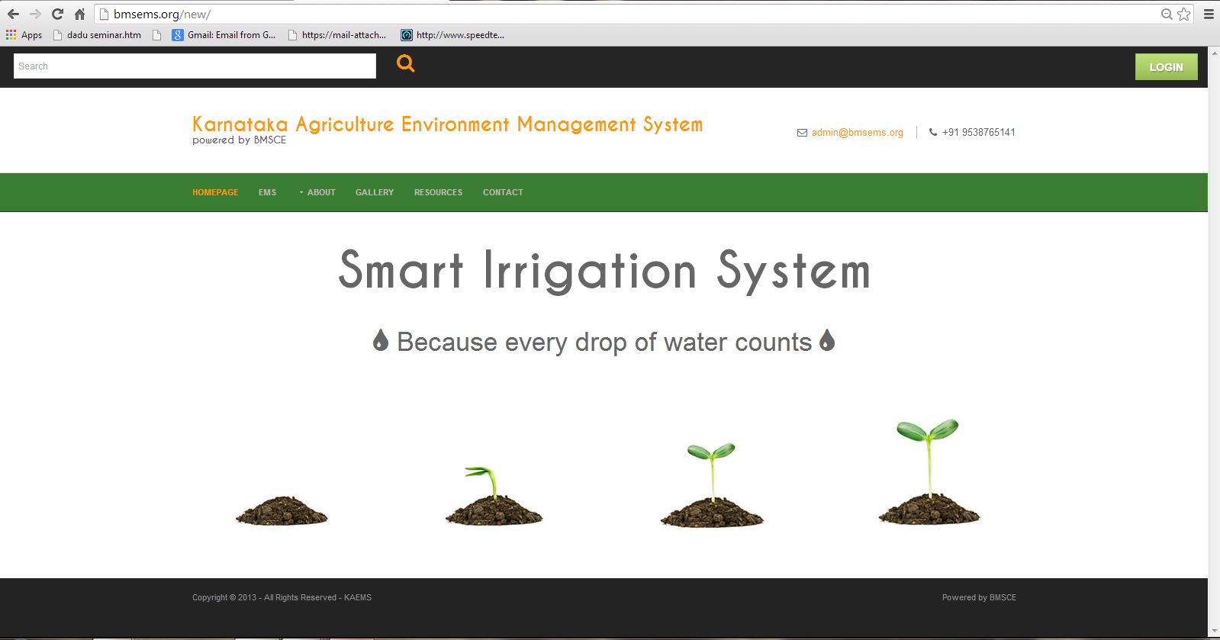
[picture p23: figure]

### Fig 3.8(a) Homepage of the website

### The web-link is: http://bmsems.org/new

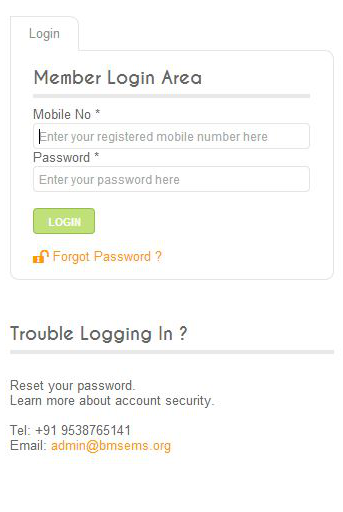
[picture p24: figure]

### Fig 3.8(b)Log-in page

Each user is provided with his own distinct ID & a secret password through which he can access the required data.

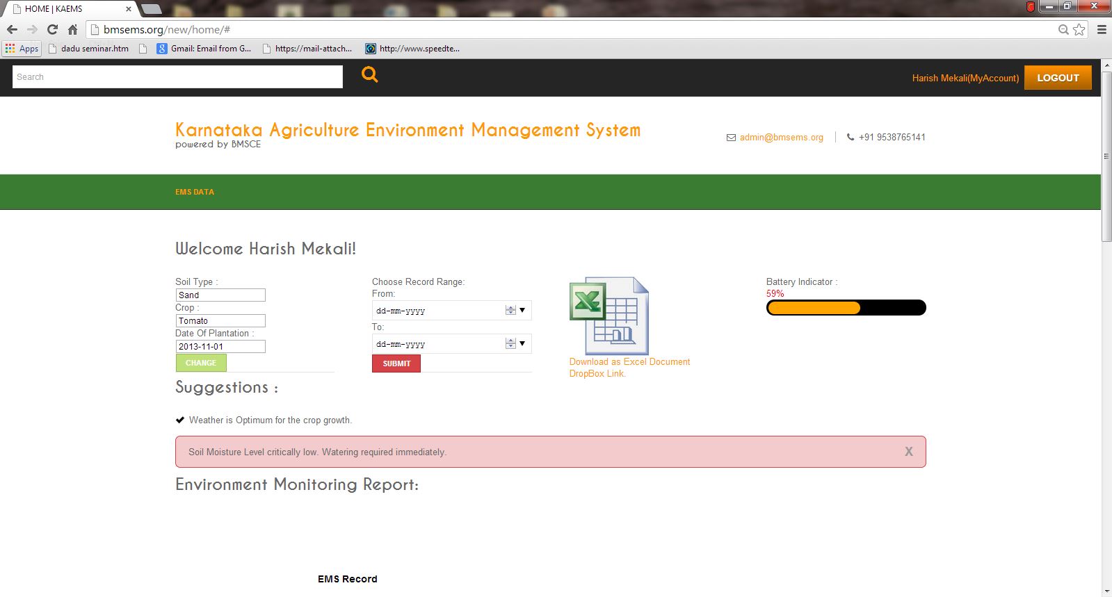
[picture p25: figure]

Fig. 3.8(c) User welcome page

The user has to login to the website as a member to access the data or use the website to read the parameter he wishes to get a hold on. For this he has to obtain the permission from the administrator.

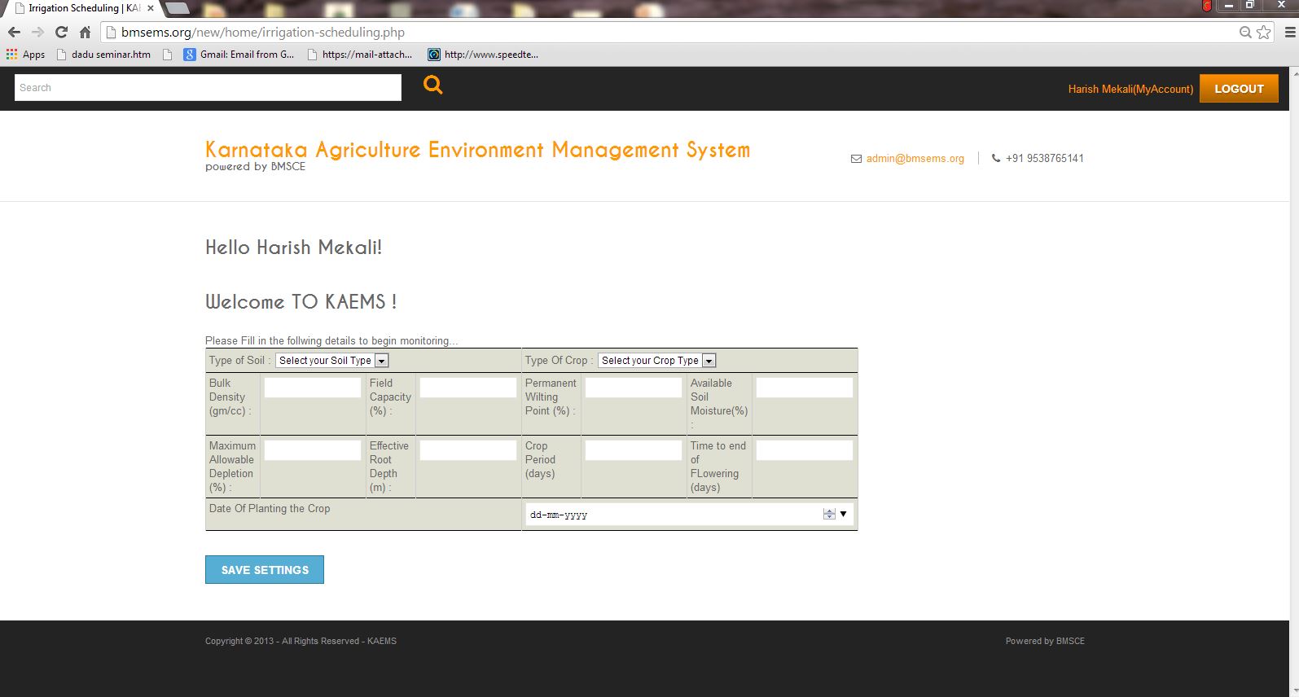
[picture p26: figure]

Fig 3.8(d) Webpage of the crop details

Initially we enter the information about soil type, crop and the date of plantation. This information is automatically updated to the database and based on this information our device controls the situation.


Fig 3.8(e) Graph

A graph displays the various sensor values employed, in detail and the output crop details along with the current battery percentage remaining.


Fig. 3.8(f) Details on an excel spreadsheet

The various sensor data are collectively stored in an excel sheet which can be used later to analyse. The excel files are maintained in an archive format so that less capacity holds maximum amount of information.

Chapter IV

CONCLUSION

We proudly propose this idea to enhance the well-being of the farmers who reside at remote places and yet obtain the knowledge of their fields and crop information. This upgradement of Data Acquisition model to Low power Data Acquisition model greatly improves the power integrity affordable by the Indian agricultural farmers. We feel glad to conclude that we have touched an effort of few technological fields, sensible utilization of water, making use of modern wireless communication such as GSM & GPRS to name a few.

Developed system proves to be best for prototype but, still some work has to be done on product development as mentioned in future work.

Each student contributed his best with the amount of technical knowledge that he possessed combined with his passion to learn further and working innovatively by participating in the project actively.

We firmly believe that our report gives you a fair idea on the project and any suggestions be it on any of the section, feedbacks and criticism are happily accepted.

Chapter V

FUTURE WORK

As in the conclusion where we did mention our inspiration to be the Weather Monitoring system (WMS) which was used as a single application in our project to monitor the soil moisture in the field along with detecting the temperature of an unknown land.

We all know that India is over-dependent on the limited power that is generated and borrowed from adjacent states. We would further like to improve our project by prioritizing at areas such as power consumption which currently feeds on battery to employing a solar cell that can power the system as well as store power for future requirements.

Once again we would like to calibrate the available moisture sensor to design our own sensor, and to make a mesh network using Zigbees so that all the units communicate with each other, send the data through the main central unit to remote place.

By completing the remaining work, the next process of this work is to send the data to the server which can be accessed through the World Wide Web as an application. Be it Android, iOS or windows platform developing a project oriented application is just few steps of passion and hard work.

Monitoring battery life for present PCB module, then to improve the battery life of the system, finally implement it in real time in the field for experiment.

RECOGNITION

Our motivations to mention a few and looking forwards to are:

(2nd runner up in the ARM Symposium held at Le Meridian, Bangalore in the year 2013)


BIBLIOGRAPHY

### 1. ‘Automated Irrigation System Using a Wireless Sensor Network and GPRS Module (http://ieeexplore.ieee.org/xpl/articleDetails.jsp?tp=&arnumber=6582678)’

By - Gutierrez, J. (http://ieeexplore.ieee.org/search/searchresult.jsp?searchWithin=p_Authors:.QT.Gutierrez,%20J..QT.&newsearch=true), Villa-Medina, J.F. (http://ieeexplore.ieee.org/search/searchresult.jsp?newsearch=true), Nieto-Garibay, A. (http://ieeexplore.ieee.org/search/searchresult.jsp?newsearch=true), Porta-Gandara M.A. (http://ieeexplore.ieee.org/search/searchresult.jsp?newsearch=true)

2. ‘Smart Orchid Soil Moisture Monitoring System Based on Wireless Communication Technology’

By- Ye Na & Liu Junfeng.

3. ‘The optimizing design and application of a new wireless Low-power universal data acquisition system’, By- Yan-fei ai1, yu-jie hao1, jian-ping li1
4. ‘Weather Monitoring System’, Project report – 2013 batch

ANNEXURE

Datasheet of Opto-coupler PC817-

Datasheet of HRS4(H) Relay-

COMPONENTS LIST

Hardware

1. Microcontroller board

Sl.No | Components | Reason for selection | Aprox cost
1. | ARM MBED Cortex – M0 LPC11U24 Microcontroller | 1. Ease of programing 2. Sponsored by ARM 3. Low power | Rs. 2500/-

2. Power supply

Sl.No | Components | Reason for selection | Aprox cost
1. | 12v-2Amp AC/DC adapter | Used as a power source | Rs. 150/-
2. | 7.4v-2Ah Lead- ion battery(rechargeable) | | Rs.800/-

3. RF(GSM) module

Sl.No | Components | Reason for selection | Aprox cost
1. | SIM900 (RS232) | Ease of interfacing /GPRS enability | Rs. 1000/-

4. Sensors
a. Soil Moisture

Sl.No | Components | Reason for selection | Aprox cost
1. | VM100 | To measure soil moisture(Non corrosive and water proof) | Rs. 3000/-

5. Switching devices

Sl.No | Components | Reason for selection | Aprox cost
1. | Relay | To drive solenoid valve | Rs. 40/-
2 | Solenoid valve | Ease of use | Rs. 350/-

6. Display device

Sl.No | Components | Reason for selection | Aprox cost
1. | Liquid Crystal Display -16x2 | Experienced usage | Rs. 130/-

7. Miscellaneous components

Sl.No | Components
1 | Wire cutter
2 | Switches
3 | Wires (Single strand and Multi strand)
4 | General PCBs
5 | Multimeter
6 | Resistor Set
7 | Buge wire
8 | Bread board
9 | Battery holder

Department of ECE | BMSCE

SMART AGRICULTURE 12

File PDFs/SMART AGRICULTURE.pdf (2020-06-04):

PROJECT REPORT
ON

## SMART AGRICULTURE

Submitted in partial fulfilment of the requirements for the award of degree of BACHELOR OF ENGINEERING
IN
ELECTRONICS AND COMMUNICATION ENGINEERING

VISVESVARAYA TECHNOLOGICAL UNIVERSITY, BELGAUM

SUBMITTED BY:
Hemantha Gowda C V | 1BM11EC406
Kaveen Kumar M K | 1BM11EC408
Nikhil D G | 1BM11EC415
Prathap J | 1BM11EC417

Under the Guidance of

## Harish V Mekali

(Assistant Professor, ECE, BMSCE)

Department of Electronics and Communication Engineering

## B.M.S COLLEGE OF ENGINEERING

(Autonomous College Affiliated to Visvesvaraya Technological University, Belgaum) Bull Temple Road, Basavanagudi, Bangalore-560019

Department of ECE | BMSCE

SMART AGRICULTURE 2

B.M.S COLLEGE (http://www.pdfcomplete.com/cms/hppl/tabid/108/Default.aspx?r=q8b3uige22) OF ENGINEERING

(Autonomous (http://www.pdfcomplete.com/cms/hppl/tabid/108/Default.aspx?r=q8b3uige22) College under VTU)

Department of Electronics and Communication Engineering

CERTIFICATE

This is to certify that the project entitled SMART AGRICULTURE is a bonafide work carried

out by Hemantha Gowda C V (USN:1BM11EC406), Kaveen Kumar M K

(USN:1BM11EC408), Nikhil D G (USN:1BM11EC415) and Prathap J (USN:1BM11EC417) in

partial fulfillment for the award of Bachelor of Engineering degree by VTU Belgaum, during the

academic year 2013-2014.

Harish V Mekali | Dr. D .Seshachalam | Dr. K.Mallikharjuna Babu
Assistant Prof., ECE, BMSCE | HOD, ECE, BMSCE | Principal, BMSCE
External Examination: | Signature with date:

1.

2.

SMART AGRICULTURE 3


SMART AGRICULTURE 4

## ABSTRACT

Our planet is progressively (http://www.pdfcomplete.com/cms/hppl/tabid/108/Default.aspx?r=q8b3uige22) marching towards a serious electric energy crisis, owing to an

escalating desire of electric energy becoming greater than its supply. We have always failed to

accept that the energy we make use of each day is restricted, yet taking it for granted. Coal,

petroleum, electric power, even water has inadequate availability. Nevertheless, we have not

taken sufficient precautions to handle a possible energy crisis. Another main concern has been the

lifespan of guided media and its loopholes to intercept and eavesdrop.

Agricultural sector has maintained a dominant position on economy and as a natural

supply for the country. Understanding the effects of heat and humidity, rain and erosion is the

need of the day. Given the recent technological improvements the world has seen, failing to make

use of it would be a sin on mankind. Here comes the need for a systematic hold on monitor of the

data. As with the increase in technological innovations, so is the increase in required source

power. An open minded effort would be to keep an eye on these available values from a remote

location, interfacing a spot-on display, along with minimal power as possible.

SMART AGRICULTURE 5

## ACKNOWLEDGEMENT

Any achievement, be it scholastic (http://www.pdfcomplete.com/cms/hppl/tabid/108/Default.aspx?r=q8b3uige22) or otherwise does not depend solely on the individual efforts but on the guidance, encouragement and cooperation of intellectuals, elders and friends. A number of personalities, in their own capacities have helped us in carrying out this project work. We would like to take this opportunity to thank them all.

We express profound gratitude to respected principal Dr. K. Mallikharjuna Babu, BMS College of Engineering for providing a congenial environment to work in.

Our sincere gratitude to Dr. D. Seshachalam, Head of the Department, Electronics and Communication Engineering for encouraging and providing this opportunity to carry out the project in the department.

We would like to thank our guide Mr. Harish V. Mekali, Assistant Professor, Department of ECE who helped us in all the ways to carry out the project work. He stood beside and guided us in every step.

Our heartfelt thanks to Dr. K. R. Suresh, Professor, Dept. of Civil Engineering, for providing valuable information regarding agriculture and funding the complete project

Our special thanks to Dr. Sadanand Gulwadi, University Relation Manager, ARM, for providing the ARM MBED Cortex-M0 boards around which project has been built.

We will be incomplete, if we don't mention our heartfelt thanks to Mr. Ashrith, 5th Sem, CSE, BMSCE for his expertise at Web Page development & the corresponding software parts.

We would like to share the joy completing the project to all the team members of NXP lab.
We thank all our professors for providing the basic knowledge without which this project wouldn't have been possible. Last but not the least we thank our family and friends, who made their valuable support compelled us to maintain a standard throughout our endeavour.

SMART AGRICULTURE 6

## SPONSOR (http://www.pdfcomplete.com/cms/hppl/tabid/108/Default.aspx?r=q8b3uige22) DETAILS

We are very much thankful to Visvesvaraya Technological University for funding the entire project.

SMART AGRICULTURE 7

TABLE (http://www.pdfcomplete.com/cms/hppl/tabid/108/Default.aspx?r=q8b3uige22) OF CONTENTS

CHAPTER | TOPIC | PAGE NO
- ABSTRACT
- ACKNOWLEDGEMENT
- LITERATURE SURVEY

### 1 INTRODUCTION

### 2 PROJECT FLOW

### 3 TESTING

### 4 CONCLUSION

### 5 FUTURE WORK

- BIBLIOGRAPHY
- RECOGNITION

SMART AGRICULTURE 8
LITERATURE (http://www.pdfcomplete.com/cms/hppl/tabid/108/Default.aspx?r=q8b3uige22) SURVEY
1. Automated Irrigation System (http://www.pdfcomplete.com/cms/hppl/tabid/108/Default.aspx?r=q8b3uige22) Using a Wireless Sensor Network and GPRS Module, (http://ieeexplore.ieee.org/xpl/articleDetails.jsp?tp=&arnumber=6582678) By -

Gutierrez, J., Villa-Medina, J.F., Nieto-Garibay, A., Porta-Gandara M.A.
- Knowledge on the design mainly consisting of wireless sensor network and wireless information unit thats based on Zigbee technology and is realized using GPRS module and concentrated on low power consumption.
- Knowledge on achieving low power consumption using PIC.
- Knowledge on sensor network powered by solar panel with rechargeable battery that works for a longer time.
- Knowledge on UART interfaces with microcontroller that can accept the data with a speed of 115.2kbps from GPRS module.

### 2. Smart Orchid Soil Moisture Monitoring System Based on Wireless Communication

Technology By- Ye Na & Liu Junfeng.
- Insight on the system cored with a Low-Power Microprocessor MSP430f149 MCU which employs smaller radiations to the environment and human body.
- Insight on achieving a wide range of influence on soil moisture and intelligent control of data in a fixed memory.
- Insight on achieving a 24hr uninterrupted monitoring.
- Insight on serial non-volatile data memory chip for storage and display device, that is based on I2C bus, in turn using multifunctional memory chip of the ferroelectric technology which contains RTC.

### 3. The optimizing design and application of a new wireless Low-power universal data

acquisition system By- Yan-fei ai1, yu-jie hao1, jian-ping li1.
- Perspective on breakthrough of traditional network communication by employing multi interface design consisting of Zigbee terminal, Zigbee router, Zigbee coordinator.
- Perspective on similar interface device connectivity with TI's chip TUSB3410 & integrated CS8900 Ethernet chip to support Ethernet interface to realize Ethernet communications; realizing serial port connectivity with PC.
- Perspective on optimization of data communication by avoiding data conflicts using hexagon method.

SMART AGRICULTURE 9

## CHAPTER I (http://www.pdfcomplete.com/cms/hppl/tabid/108/Default.aspx?r=q8b3uige22)

## INTRODUCTION

Agriculture uses 85% of available fresh water resources worldwide and this percentage will continue to be dominant in water consumption because of population growth and increased food demand. There is an urgent need to create strategies based on science and technology for sustainable use of water, including technical, agronomic, managerial and institutional improvements. For every 18 months the demand for electric based requirements increases two-fold.

The proposed project has been our brain child on such a low power DAS. We have proudly maintained a check on power requirement the without degrading the quality of it. This low power data acquisition system can be used in farm fields for acquiring the values of temperature and humidity using sensors.

### 1.1 WEATHER MONITORING SYSTEM

We would like to begin by introducing our head start, another similar important project WEATHER MONITORING SYSTEM by a fellow college mate Mr. Nithin whose work is based on monitoring the various factors of weather. We happily like to extend that this project has been successfully completed with the required outcomes matching his expectations.


FIG 1.1(A): Depicts the transmitter part of the embedded system where the sensors read the values and sends them to a mobile phone in the form of SMS through GSM Module.

SMART AGRICULTURE 10


FIG 1.1(B): Receiver part of the embedded system where messages received for every 15 mins will be stacked in the mobile storage.

SMS Format will be as given below.

FIG 1.1(C): Output working where get the graph of the corresponding parameter as shown above.

The aim of the project is to get the graph of the required parameter values.

### 1.2 Proposed Problem

But the qualitative output comes at a cost of the power required. The power consumption is relevantly high to the expected working. In a single statement the problem can be pointed as

No Data Acquisition System at a remote area is perfect unless it works at a considerably low power & extended battery life at least for a duration of year and more.

Temp:29⁰C
SM:25%
ST:18⁰C
Lum:100lu
x RH:20%

SMART AGRICULTURE 11

### 1.3 Diagnosed solution

Our innovation Smart Agriculture (http://www.pdfcomplete.com/cms/hppl/tabid/108/Default.aspx?r=q8b3uige22) can be called as a successor of the above mentioned WMS. (http://www.pdfcomplete.com/cms/hppl/tabid/108/Default.aspx?r=q8b3uige22)

As a sensible world resident, we begin by investigating alternative power solutions and
advancement in technology, for | | example solar, wind electric energy and LDOs respectively.
Utilizing these alternative energy solutions | in as a whole is comparatively realistic and cheap to
modern day units. | Technical solutions, previously accomplished using Analog circuitry, have
been converted into data acquisition systems that translate Analog input signals into digital information and process the binary data. With a few additional ideas to decrease the power consumption by employing solar cells and the improved features provided by ARM such as Sleep Mode we lend a heavy help.

### 1.4 Implementation Model

Microcontroller: ARM Cortex M0 works as the heart of the project. It controls the output peripherals depending on the input sensor thresholds.

Sensors: Variety of sensors are used to detect the physical conditions of the environment such as moisture, temperature, humidity etc.

LCD Display: LCD 16x2 Display employed displays the various parameters of the sensors.

Solar Panel Battery: The Solar panel helps in providing power by acquiring the energy from the Suns rays. This in-turn is fed to the battery employed for storage and future uses.

GSM: A GSM module is employed in the project such that the read values are not only displayed but also available online through the internet connection.

## Battery

## Internet

SMART AGRICULTURE; 1.5 Block Diagram; Display; ARM Cortex; GPRS; Sensors; Memory

Fig. 1.5 Conceptual block diagram of the model

SMART AGRICULTURE | 13
CHAPTER II (http://www.pdfcomplete.com/cms/hppl/tabid/108/Default.aspx?r=q8b3uige22) | PROJECT FLOW

## 2.1 COMPONENTS USED

- ARM CORTEX M0 LPC11U24
- LCD 16x2 DISPLAY
- PC817 OPTO-COUPLER
- SIM900 GSM MODULE
- DC-12V RELAY
- MOISTURE SENSOR

### 2.2 HARDWARES:

### 2.2.1 ARM CORTEX M0 LPC11U24:


FIG. 2.2.1 ARM Cortex-M0

### 2.2.2 General description

- The LPC11U2x are an ARM Cortex-M0 based, low-cost 32-bit MCU family, designed for 8/16-bit microcontroller applications, offering performance, low power, simple instruction set and memory addressing together with reduced code size compared to existing 8/16-bit architectures.
- The LPC11U2x operate at CPU frequencies of up to 50 MHz
- Equipped with a highly flexible and configurable full -Speed USB 2.0 device controller, the LPC11U2x brings unparalleled design flexibility and seamless integration to todays demanding connectivity solutions.

SMART AGRICULTURE 14

- The peripheral complement (http://www.pdfcomplete.com/cms/hppl/tabid/108/Default.aspx?r=q8b3uige22) of the LPC11U2x includes up to 32 kB of flash memory, up to 10 kB of SRAM data memory (http://www.pdfcomplete.com/cms/hppl/tabid/108/Default.aspx?r=q8b3uige22) and 4 kB EEPROM, one Fast -mode Plus I²
C-bus interface,
one RS-485/EIA-485 USART (http://www.pdfcomplete.com/cms/hppl/tabid/108/Default.aspx?r=q8b3uige22) with support for synchronous mode and smart card interface, two SSP interfaces, four general- purpose counter/timers, a 10-bit ADC (Analogy-to-Digital Converter), and up to 54 general-purpose I/O pins.

## 2.3 Features and benefits

### 2.3.1 System:

- ARM Cortex-M0 processor, running at frequencies of up to 50 MHz
- ARM Cortex-M0 built-in Nested Vectored Interrupt Controller (NVIC).
- Non-Maskable Interrupt (NMI) input selectable from several input sources.
- System tick timer.

### 2.3.2 Memory:

- Up to 32 kB on-chip flash program memory.
- Up to 4 kB on-chip EEPROM data memory; byte erasable and byte programmable.
- Up to 10 kB SRAM data memory.
- 16 kB boot ROM.
- In-System Programming (ISP) and In-Application Programming (IAP) for flash and EEPROM via on-chip bootloader software.
- ROM-based USB drivers. Flash updates via USB supported.
- ROM-based 32-bit integer division routines.

### 2.3.3 Debug options:

- Standard JTAG (Joint Test Action Group) test interface for BSDL (Boundary Scan Description Language).
- Serial Wire Debug.

### 2.3.6 Serial interfaces:

- USB 2.0 full-speed device controller.
- USART (Universal Synchronous Asynchronous Receiver/Transmitter) with fractional baud rate generation, internal FIFO, a full modem control handshake interface, and support for RS-485/9-bit mode and synchronous mode. USART supports an asynchronous smart card interface (ISO 7816-3).
- Two SSP (Synchronous Serial Port) controllers with FIFO and multi-protocol capabilities.
- I

2

C-bus interface supporting the full I²
C-bus specification and Fast-mode Plus with a data rate of up to 1 Mbit/s with multiple address recognition and monitor mode.

### 2.3.5 Analog peripherals:

SMART AGRICULTURE 15

- 10-bit ADC with input (http://www.pdfcomplete.com/cms/hppl/tabid/108/Default.aspx?r=q8b3uige22) multiplexing among eight pins.

## SMART AGRICULTURE 16

### 2.3.4 Digital peripherals:

- Up to 54 General-Purpose (http://www.pdfcomplete.com/cms/hppl/tabid/108/Default.aspx?r=q8b3uige22) I/O (GPIO) pins with configurable pull-up/pull-down resistors, repeater mode, and open-drain mode.
- Up to 8 GPIO pins can be selected as edge and level sensitive interrupt sources.
- Two GPIO grouped interrupt modules enable an interrupt based on a programmable pattern of input states of a group of GPIO pins.
- High-current source output driver (20 mA) on one pin.
- High-current sink driver (20 mA) on true open-drain pins.
- Four general-purpose counter/timers with a total of up to 5 capture inputs and 13 match outputs.
- Programmable Windowed WatchDog Timer (WWDT) with a dedicated, internal low-power WatchDog Oscillator (WDO)

### 2.3.7 Clock generation:

- Crystal Oscillator with an operating range of 1 MHz to 25 MHz (system oscillator).
- 12 MHz high-frequency Internal RC oscillator (IRC) that can optionally be used as a system clock.
- Internal low-power, low-frequency WatchDog Oscillator (WDO) with programmable frequency output.
- PLL allows CPU operation up to the maximum CPU rate with the system oscillator or the IRC as clock sources.
- A second, dedicated PLL is provided for USB.
- Clock output function with divider that can reflect the crystal oscillator, the main clock, the IRC, or the watchdog oscillator.

### 2.3.8 Power control:

- Integrated PMU (Power Management Unit) to minimize power consumption during Sleep, Deep-sleep, Power-down, and Deep power-down modes.
- Power profiles residing in boot ROM provide optimized performance and minimized power consumption for any given application through one simple function call.
- Four reduced power modes: Sleep, Deep-sleep, Power-down, and Deep power-down.
- Processor wake-up from Deep-sleep and Power-down modes via reset, selectable GPIO pins, watchdog interrupt, or USB port activity.
- Processor wake-up from Deep power-down mode using one special function pin.
- Power-On Reset (POR).
- Brownout detects with four separate thresholds for interrupt and forced reset.
- Unique device serial number for identification.
- Single 3.3 V power supply (1.8 V to 3.6 V).
- Temperature range 40 C to +85 C.
- Available as LQFP64, LQFP48, TFBGA48, and HVQFN33 packages.

### 2.3.9 Applications:

- Hand held scanners (http://www.pdfcomplete.com/cms/hppl/tabid/108/Default.aspx?r=q8b3uige22)
- Medical
- Consumer peripherals
- USB Audio devices
- Industrial control


FIG. 2.4(A) ARM CORTEX M0 ARCHITECHTURE


2.4(B) TOP VIEW OF CORTEX M0

### 2.4 LCD 16x2 DISPLAY

FIG. 2.4 LCD 16X2 DISPLAY

LCD (Liquid Crystal Display): A 16x2 LCD display is very basic module and is very commonly used in various devices and circuits. These modules are preferred over seven segments and other multi segment LEDs. The reasons being: LCDs are economical; easily programmable; have no limitation of displaying special & even custom characters (unlike in seven segments) animations and so on.

A 16x2 LCD means it can display 16 characters per line and there are 2 such (http://www.engineersgarage.com/microcontroller/8051projects/create-custom-characters-LCD-AT89C51) lines. In this LCD each character (http://www.engineersgarage.com/microcontroller/8051projects/display-custom-animations-LCD-AT89C51) is displayed in 5x7 pixel matrix. This LCD has two registers, namely, Command and Data.

The command register stores (http://www.pdfcomplete.com/cms/hppl/tabid/108/Default.aspx?r=q8b3uige22) the command instructions given to the LCD. A command is an instruction given to LCD to do a predefined (http://www.pdfcomplete.com/cms/hppl/tabid/108/Default.aspx?r=q8b3uige22) task like initializing it, clearing its screen, setting the cursor position, controlling display etc. The data register stores the data to be displayed on the LCD. The data is the ASCII value of the character to be displayed on the LCD. Click to learn more about internal structure of a LCD.

### 2.4.1 Pin Description:

Pin No | Function | Name
1 | Ground (0V) | Ground
2 | Supply voltage; 5V (4.7V 5.3V) | Vcc
3 Contrast adjustment; through a variable | resistor | VEE
4 Selects command register when low; and | data register when high | Register Select
5 Low to write to the register; High to read | from the register | Read/write
6 Sends data to data pins when a high to low | pulse is given | Enable
7 8 DB1 9 DB2 10 DB3 11 DB4 12 DB5 13 DB6 14 DB7 | 8-bit data pins | DB0
15 | Backlight VCC (5V) | Led+
16 | Backlight Ground (0V) | Led-

TABLE 2.4.1 PIN DESCRIPTION OF LCD 16X2 DISPLAY

2.5 OPTO-COUPLER: (http://www.pdfcomplete.com/cms/hppl/tabid/108/Default.aspx?r=q8b3uige22)


FIG. 2.5(A) OPTO-COUPLER IC

The HCPL-817 contains a light emitting diode optically coupled to a phototransistor. It is packaged in a 4-pin DIP package and available in wide-lead spacing option and lead bend SMD option. Input-output isolation voltage is 5000 Vrms. Response time, tr, is typically 4 µs and minimum CTR is 50% at input current of 5 mA.

`

FIG. 2.5(B) INTERNAL CONNECTION AND SCHEMATIC OF OPTO-COUPLER IC PC817

2.6 SIM900 GSM MODULE: (http://www.pdfcomplete.com/cms/hppl/tabid/108/Default.aspx?r=q8b3uige22)

You need only two wires (TX, RX) except Power supply to interface with microcontroller / Arduino. The built in Power supply allows you to connect wide range unregulated power supply. Using this modem, you can send SMS, data and read SMS through simple AT command.


FIG. 2.6 SIM900 GSM MODULE

This is a complete Quad-band GSM/GPRS module in a SMT type and designed with a very powerful single-chip processor integrating AMR926EJ-S core, allowing you to benefit from small dimensions and cost-effective solutions.

Featuring | an | industry-standard | interface, | the | SIM900 | delivers | GSM/GPRS
850/900/1800/1900MHz performance for voice, SMS, Data, and Fax in a small form factor and with low power consumption. With a tiny configuration of 24mm x 24mm x 3 mm, SIM900 can fit almost all the space requirements in your M2M applications, especially for slim and compact demands of design.

2.6.1 General features: (http://www.pdfcomplete.com/cms/hppl/tabid/108/Default.aspx?r=q8b3uige22)

* Quad-Band 850/ 900/ 1800/ 1900 MHz * GPRS multi-slot class 10/8
* GPRS mobile station class B
* Compliant to GSM phase 2/2+
Class 4 (2 W @850/ 900 MHz) Class 1 (1 W @ 1800/1900MHz)
* Dimensions: 24*24*3mm
* Weight: 3.4g
* Control via AT commands (GSM 07.07 ,07.05 and SIMCOM enhanced AT Commands)
* SIM application toolkit
* Supply voltage range : 3.2 ... 4.8V
* Low power consumption: 1.0mA(sleep mode) * Operation temperature: -40°C to +85 °C

### 2.6.2 Specifications for SMS via GSM/GPRS:

* Point to point MO and MT
* SMS cell broadcast
* Text and PDU mode

### 2.6.3 Software features:

* 0710 MUX protocol
* embedded TCP/UDP protocol * FTP/HTTP

### 2.6.4 Special firmware:

* FOTA

* MMS

* Java (cooperate with Isolation)

* Embedded AT

2.7 (http://www.pdfcomplete.com/cms/hppl/tabid/108/Default.aspx?r=q8b3uige22) DC-12V RELAY:


FIG. 2.7 RELAY

A relay is an electrical switch that uses an electromagnet to move the switch from the off to on position instead of a person moving the switch. It takes a relatively small amount of power to turn on a relay but the relay can control something that draws much more power.

### 2.7.1 OPERATION OF RELAY:

Relays (and switches) come in different configurations. The most common are shown to the right. Single Pole Single Throw (SPST) is the simplest with only two contacts. Single Pole Double Throw (SPDT) has three contacts. The contacts are usually labelled Common (COM), Normally Open (NO), and Normally Closed (NC). The Normally Closed contact will be connected to the Common contact when no power is applied to the coil. The Normally Open contact will be open (i.e. not connected) when no power is applied to the coil. When the coil is energized the Common is connected to the Normally Open contact and the Normally Closed contact is left floating. The Double Pole versions are the same as the Single Pole version except there are two switches that open and close together. Select a relay with contacts that can handle the voltage and current requirements of the load. Keep in mind that some loads (such as motors) draw much more current when first turned on than they do at steady state. Select a relay with a coil voltage and current that you can control easily. Ex: If you want to turn on the AC unit with a 12VDC power supply get a 12VDC coil. Note: Coils will be rated for either AC or DC.


FIG. 2.7.1 RELAY OPERATION

### 2.7.2 The primary functions of a relay are:

- The galvanic separation of the primary or actuating circuit and the load circuits
- Single input/multiple output capability
- Separation of different load circuits for multi-pole relays
- Separation of AC and DC circuits
- Interface between electronic and power circuits
- Multiple switching functions, e.g. delay, signal conditioning
- Amplifier function.

### 2.7.3 Applications of Relay:

Typical applications for relays include laboratory instruments, telecommunication systems, computer interfaces, domestic appliances, air conditioning and heating, automotive electrics, traffic control, lighting control, building control, electric power control, business machines, control of motors and solenoids, tooling machines, production and test equipment.

### 2.8 SENSORS: (http://www.pdfcomplete.com/cms/hppl/tabid/108/Default.aspx?r=q8b3uige22)


FIG 2.8 VH400 MOISTURE SENSOR

### 2.8.1 Moisture Sensor:

High frequency VH400 series soil moisture sensor probes enable precise low cost monitoring of soil water content. Because our probe measures the dielectric constant of the soil using transmission line techniques, it is insensitive to water salinity, and will not corrode over time as does conductivity based probes. Our probes are small, rugged, and low power.

Compared to other low cost sensor such as gypsum block sensors, our probes offer a rapid response time. They can be inserted and take an accurate reading in under 1 second.

The VH400 operates at a much higher frequency and it is much more sensitive at higher VWC levels, and its curves are more linear.

Probes come standard with a 2 meter cable.

2.8.2 Soil Moisture Sensor (http://www.pdfcomplete.com/cms/hppl/tabid/108/Default.aspx?r=q8b3uige22) Probe Applications:

- Irrigation and sprinkler systems.
- Moisture monitoring of bulk foods.
- Rain and weather monitoring.
- Environmental monitoring.
- Water conservation applications.
- Fluid level measurements.

### 2.8.3 Soil Moisture Sensor Probe Features:

- Extreme low cost with volume pricing.
- Not conductivity based.
- Insensitive to salinity.
- Probe does not corrode over time.
- Rugged design for long term use.
- Small size.
- Consumes less than 600uA for very low power operation.
- Precise measurement.
- Measures volumetric water content (VWC) or gravimetric water content (GWC).
- Patent pending technology.
- Output Voltage is proportional to moisture level.
- Wide supply voltage range.
- Can be buried and is water proof.
- Probe is long and slender for wider use, including smaller potted plants.

Chapter III (http://www.pdfcomplete.com/cms/hppl/tabid/108/Default.aspx?r=q8b3uige22) | TESTING


FIG 3.0 GENERAL REPRESENTATION OF A BREAD-BOARD

We initiated our idea on a General Bread-Board at the beginning. Our academics helped us to understand the basic model of a bread-board such that the connections upon it can be carried on with ease. Understanding of the internal connections is an important aspect with respect to the connections made upon it.

The overall project was carried forward by mounting the corresponding components on the Bread-Board as per the schematic.

### 3.1 ARM CORTEX M0:

FIG 3.1 AN ARM IC ON A BREAD BOARD

ARM Cortex was the utmost (http://www.pdfcomplete.com/cms/hppl/tabid/108/Default.aspx?r=q8b3uige22) main component that we wished to test first by embedding it on the bread-board and through the interfacing (http://www.pdfcomplete.com/cms/hppl/tabid/108/Default.aspx?r=q8b3uige22) of USB connector. It was tested by using our knowledge of the online compiler.

The purpose to use ARM Cortex- M0 is because of the fact that it is the lowest power consuming IC available from the family of ARM Controllers.

### 3.2 LCD DISPLAY:


FIG. 3.2 LCD 16X2 DISPLAY

The next step of our testing was occupied by the output device LCD 16x2 Display. We found it more important to display our outcomes through a device that can be more of an understanding to the outward world.

We even went to the extent of displaying our names quite naively.

### 3.3 Opto-coupler and Relay:


FIG 3.3 CONNECTION OF OPTO-COUPLER AND RELAY

We followed the interfacing cycle (http://www.pdfcomplete.com/cms/hppl/tabid/108/Default.aspx?r=q8b3uige22) next by an opto-coupler. We followed it up with a relay to drive the solenoid valve. The main (http://www.pdfcomplete.com/cms/hppl/tabid/108/Default.aspx?r=q8b3uige22) reason for using this opto-coupler was to provide isolation between the relay and the controller on one side. Also when the solenoid valve turns on it produces a back-emf which may turn out to be harmful to the controller. So in order to provide this very required isolation we employed the opto-coupler.

### 3.4 Sensors:

Our need was fed by the values from the sensors that we employed. The moisture sensor was used to sense the moisture level of the soil which was inturn fed to the controller. We set a calibrating threshold as per our required level. The programming was such that when the sensor value exceeded the threshold the controller provided the control signal to turn off the solenoid valve.

### 3.5 Final Working Model:


FIG 3.5 FINAL WORKING MODULE ON A PCB

### 3.6 SOFTWARES: (http://www.pdfcomplete.com/cms/hppl/tabid/108/Default.aspx?r=q8b3uige22)

### 1. System Software

Sl.No | Components | Reason for selection | Approx. cost
1. | Windows XP/7 OS | Experienced usage | -

### 2. Programming/Coding software

Sl.No | Components | Reason for selection | Approx. cost
1 | Mbed online compiler | C++ coding for ARM MBED board | -
2 | PHP Programming language | Basic web-page language | -

### 3. Application Software

Sl.No | Components | Reason for selection | Approx. cost
1. | Eagle layout editor 6.5.0 | PCB design | -
2 | HyperTerminal | Interfacing external modules to computer(PC/Laptop) | -

FIG 3.5 TABLES OF SOFTWARE USED

### 3.7 Software Layout:

On the other hand simultaneously we developed a model of the project on the PC as a soft format using Eagle 6.5.0. Though none of us was an expert on the field we managed to learn it and create a schematic and board layout.


FIG. 3.7(A) FRONT VIEW OF PCB LAYOUT

FIG 3.7(B) REAR VIEW

3.8 REMOTE DATA (http://www.pdfcomplete.com/cms/hppl/tabid/108/Default.aspx?r=q8b3uige22) ACQUISITION:

We provide an alternate method of interfacing the output not just with a display but also uploading the parameters to the internet through a GSM Module. Any user in need of knowing the information can log-in with his identity & a distinct secure password and can obtain it.


FIG 3.8(A) HOMEPAGE OF THE WEBSITE

The web-link is: http://bmsems.org/new


FIG 3.8(B) LOG-IN PAGE

Each user is provided with his own distinct ID & a secret password through which he can access the required data.


FIG. 3.8(C) USER WELCOME PAGE

The user has to login to the website as a member to access the data or use the website to read the parameter he wishes to get a hold on. For this he has to obtain the permission from the administrator.


FIG 3.8(D) WEBPAGE OF THE CROP DETAILS

Initially we enter the information about soil type, crop and the date of plantation. This information is automatically updated to the database and based on this information our device controls the situation.

FIG 3.8(E) GRAPH

A graph displays the various sensor values employed, in detail and the output crop details along with the current battery percentage remaining.


FIG. 3.8(F) DETAILS ON AN EXCEL SPREADSHEET

The various sensor data are collectively stored in an excel sheet which can be used later to analyse. The excel files are maintained in an archive format so that less capacity holds maximum amount of information.

Chapter IV (http://www.pdfcomplete.com/cms/hppl/tabid/108/Default.aspx?r=q8b3uige22) | CONCLUSION

We proudly propose this idea to enhance the well-being of the farmers who reside at remote places and yet obtain the knowledge of their fields and crop information. This upgradement of Data Acquisition model to Low power Data Acquisition model greatly improves the power integrity affordable by the Indian agricultural farmers. We feel glad to conclude that we have touched an effort of few technological fields, sensible utilization of water, making use of modern wireless communication such as GSM & GPRS to name a few.

Developed system proves to be best for prototype but, still some work has to be done on product development as mentioned in future work.

Each student contributed his best with the amount of technical knowledge that he possessed combined with his passion to learn further and working innovatively by participating in the project actively.

We firmly believe that our report gives you a fair idea on the project and any suggestions be it on any of the section, we happily accept feedbacks and criticism.

Chapter V (http://www.pdfcomplete.com/cms/hppl/tabid/108/Default.aspx?r=q8b3uige22) | FUTURE WORK

As in the conclusion where we did mention our inspiration to be the Weather Monitoring system (WMS) which was used as a single application in our project to monitor the soil moisture in the field along with detecting the temperature of an unknown land.

We all know that India is over-dependent on the limited power that is generated and borrowed from adjacent states. We would further like to improve our project by prioritizing at areas such as power consumption which currently feeds on battery to employing a solar cell that can power the system as well as store power for future requirements. We

Once again we would like to calibrate the available moisture sensor to design our own sensor, and to make a mesh network using Zigbees so that all the units communicate with each other, send the data through the main central unit to remote place.

By completing the remaining work, the next process of this work is to send the data to the server which can be accessed through the World Wide Web as an application. Be it Android, iOS or windows platform developing a project oriented application is just few steps of passion and hard work. Monitoring battery life for present PCB module, then to improve the battery life of the system, finally implement it in real time in the field for experiment.

## RECOGNITION

Our motivations to mention (http://www.pdfcomplete.com/cms/hppl/tabid/108/Default.aspx?r=q8b3uige22) a few and looking forwards to are:

- 2nd runner up in the ARM Symposium held at Le Meridian, Bangalore in the year 2013.

(ARM COMPETETORS, GUIDES & DELIGATES)

## BIBLIOGRAPHY (http://www.pdfcomplete.com/cms/hppl/tabid/108/Default.aspx?r=q8b3uige22)

### 1. Automated Irrigation System Using a Wireless Sensor Network and GPRS Module

By - Gutierrez, J., Villa-Medina, J.F., Nieto-Garibay, A., Porta-Gandara M.A. (http://ieeexplore.ieee.org/xpl/articleDetails.jsp?tp=&arnumber=6582678)

2. Smart Orchid Soil Moisture Monitoring System Based on Wireless Communication Technology By- Ye Na & Liu Junfeng.
3. The optimizing design and application of a new wireless Low-power universal data acquisition system, By- Yan-fei ai1, yu-jie hao1, jian-ping li1

### 4. Weather Monitoring System, Project report 2013 batch

## ANNEXURE

Datasheet of Opto-coupler PC817- (http://www.pdfcomplete.com/cms/hppl/tabid/108/Default.aspx?r=q8b3uige22)



Datasheet of HRS4(H) (http://www.pdfcomplete.com/cms/hppl/tabid/108/Default.aspx?r=q8b3uige22) Relay-

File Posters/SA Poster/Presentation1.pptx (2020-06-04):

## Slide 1


SMART AGRICULTURE

DEPARTMENT OF ELECTRONICS & COMMUNICATION
IN COLABORATION WITH
DEPARTMENT OF CIVIL ENGINEERING

Agriculture may be the backbone of Indian economy yet is unfortunately at the of backdoor Indian gate

Smart Agriculture is arguably an affordable boon dedicated to our beloved farmers


Not just available as a real time monitoring but also on web around the globe in this internet driven era

2nd runner up at the ARM symposium is just the needed motivation of many more to follow

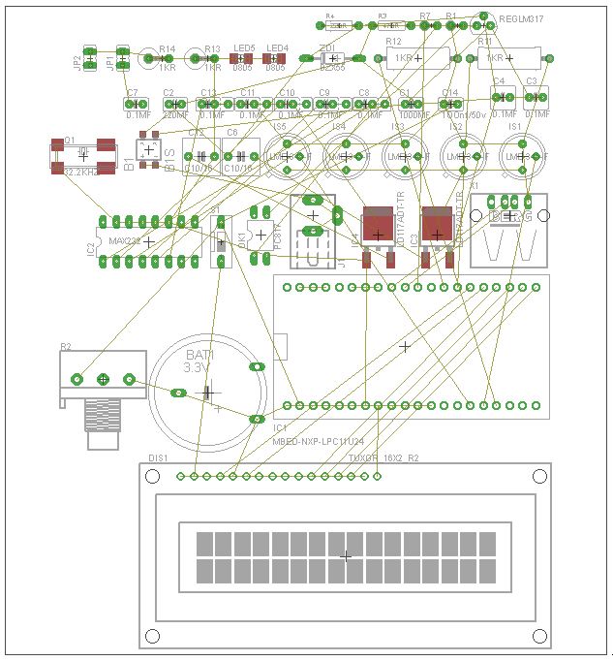
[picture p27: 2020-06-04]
Images/schematic_b.JPG

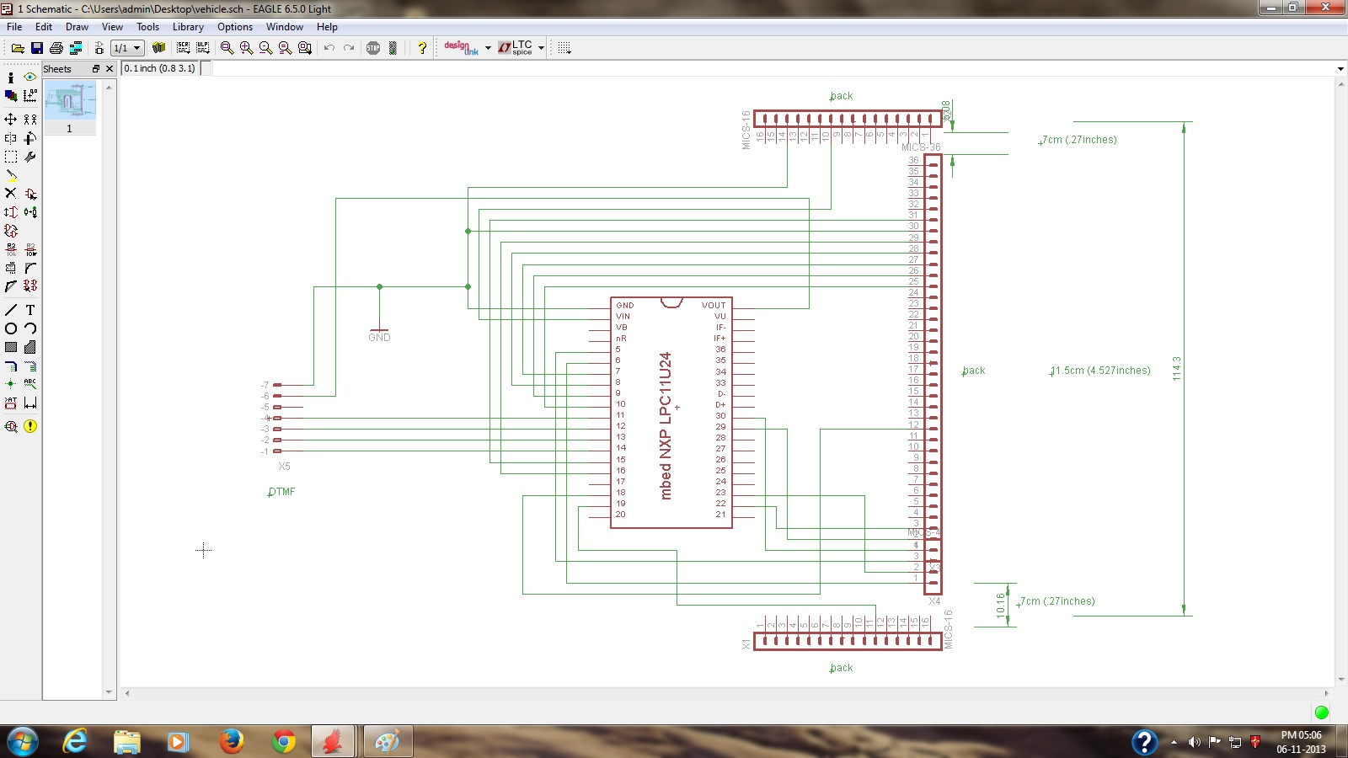
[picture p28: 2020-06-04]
Images/vehicle schematic.jpg

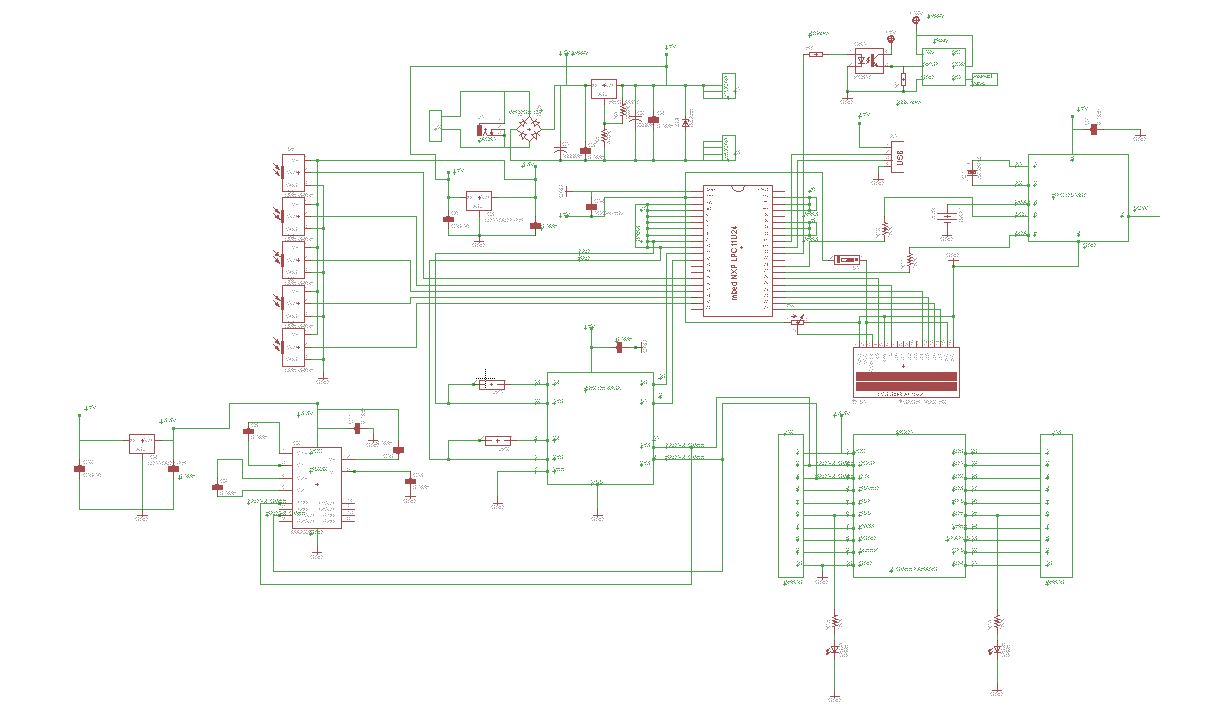
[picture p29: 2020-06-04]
Images/schematic_f.JPG

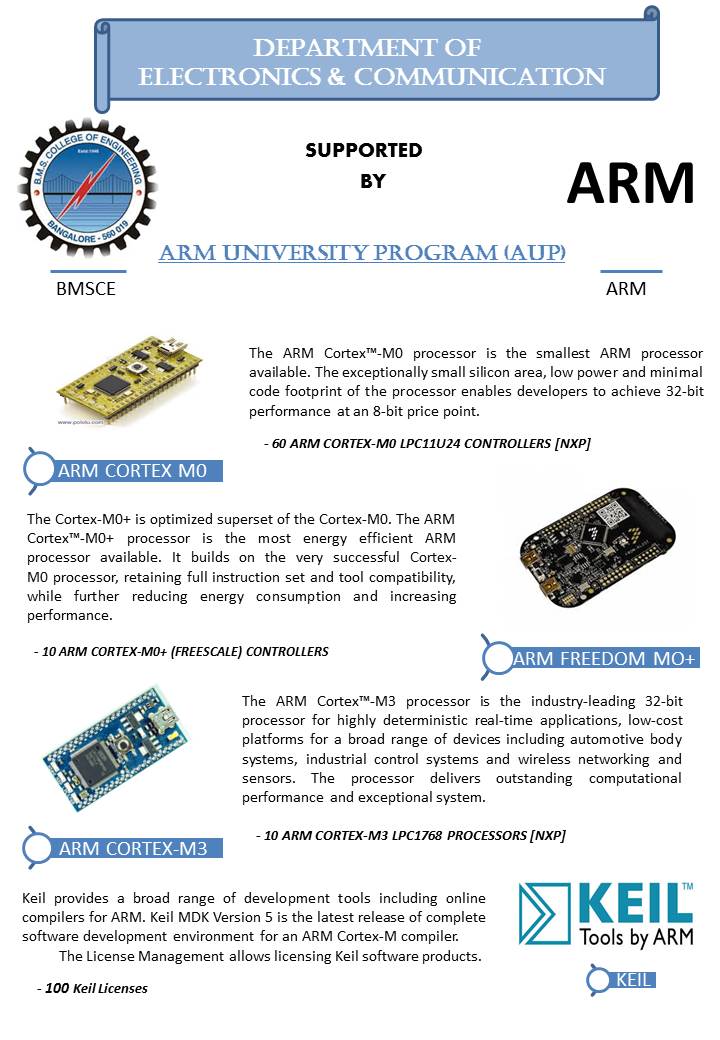
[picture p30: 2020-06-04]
Posters/ARM Poster/ARM poster.jpg

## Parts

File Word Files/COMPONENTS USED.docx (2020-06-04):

## COMPONENTS USED

- ARM CORTEX MICROCONTROLLER
- SOIL MOISTURE SENSOR
- LCD DISPLAY
- OPTO-COUPLER
- RELAY
- ZIGBEE MODULE
- GSM MODULE
- REAL TIME CLOCK
- USB
- SOLAR PANEL

## ARM CORTEX M0 LPC11U24:

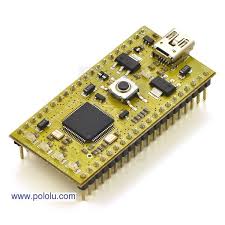
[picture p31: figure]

ARM Cortex-M0

## General description:

- The LPC11U2x are an ARM Cortex-M0 based, low-cost 32-bit MCU family, designed for 8/16-bit microcontroller applications, offering performance, low power, simple instruction set and memory addressing together with reduced code size compared to existing 8/16-bit architectures.
- The LPC11U2x operate at CPU frequencies of up to 50 MHz
- Equipped with a highly flexible and configurable full -Speed USB 2.0 device controller, the LPC11U2x brings unparalleled design flexibility and seamless integration to today’s demanding connectivity solutions.
- The peripheral complement of the LPC11U2x includes up to 32 kB of flash memory, up to 10 kB of SRAM data memory and 4 kB EEPROM, one Fast -mode Plus I²C-bus interface, one RS-485/EIA-485 USART with support for synchronous mode and smart card interface, two SSP interfaces, four general- purpose counter/timers, a 10-bit ADC (Analogy-to-Digital Converter), and up to 54 general-purpose I/O pins.

## VH400 SOIL MOISTURE SENSOR:


VH400 Moisture sensor

High frequency VH400 series soil moisture sensor probes enable precise low cost monitoring of soil water content. Because our probe measures the dielectric constant of the soil using transmission line techniques, it is insensitive to water salinity, and will not corrode over time as does conductivity based probes. Our probes are small, rugged, and low power.

Compared to other low cost sensor such as gypsum block sensors, our probes offer a rapid response time. They can be inserted and take an accurate reading in under 1 second.

The VH400 operates at a much higher frequency and it is much more sensitive at higher VWC levels, and its curves are more linear. Probes come standard with a 2 meter cable.

## Soil Moisture Sensor Probe Applications:

- Irrigation and sprinkler systems.
- Moisture monitoring of bulk foods.
- Rain and weather monitoring.
- Environmental monitoring.
- Water conservation applications.
- Fluid level measurements.

## Soil Moisture Sensor Probe Features:

- Extreme low cost with volume pricing.
- Not conductivity based.
- Insensitive to salinity.
- Probe does not corrode over time.
- Rugged design for long term use.
- Small size.
- Consumes less than 600uA for very low power operation.
- Precise measurement.
- Measures volumetric water content (VWC) or gravimetric water content (GWC).
- Patent pending technology.
- Output Voltage is proportional to moisture level.
- Wide supply voltage range.
- Can be buried and is water proof.
- Probe is long and slender for wider use, including smaller potted plants.

## LCD 16x2 DISPLAY

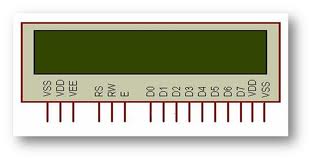
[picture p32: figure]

LCD 16x2 Display

LCD (Liquid Crystal Display): A 16x2 LCD display is very basic module and is very commonly used in various devices and circuits. These modules are preferred over seven segments (http://www.engineersgarage.com/content/seven-segment-display) and other multi segment LED (http://www.engineersgarage.com/content/led)s. The reasons being: LCDs are economical; easily programmable; have no limitation of displaying special & even custom characters (http://www.engineersgarage.com/microcontroller/8051projects/create-custom-characters-LCD-AT89C51) (unlike in seven segments) animations (http://www.engineersgarage.com/microcontroller/8051projects/display-custom-animations-LCD-AT89C51) and so on.

A 16x2 LCD means it can display 16 characters per line and there are 2 such lines. In this LCD each character is displayed in 5x7 pixel matrix. This LCD has two registers, namely, Command and Data.

The command register stores the command instructions given to the LCD. A command is an instruction given to LCD to do a predefined task like initializing it, clearing its screen, setting the cursor position, controlling display etc. The data register stores the data to be displayed on the LCD. The data is the ASCII value of the character to be displayed on the LCD. Click to learn more about internal structure of a LCD (http://www.engineersgarage.com/insight/how-lcd-works).

## Pin Description:

Pin No | Function | Name
1 | Ground (0V) | Ground
2 | Supply voltage; 5V (4.7V – 5.3V) | Vcc
3 | Contrast adjustment; through a variable resistor | VEE
4 | Selects command register when low; and data register when high | Register Select
5 | Low to write to the register; High to read from the register | Read/write
6 | Sends data to data pins when a high to low pulse is given | Enable
7 | 8-bit data pins | DB0
8 | | DB1
9 | | DB2
10 | | DB3
11 | | DB4
12 | | DB5
13 | | DB6
14 | | DB7
15 | Backlight VCC (5V) | Led+
16 | Backlight Ground (0V) | Led-

Pin description of LCD 16x2 Display

## OPTO-COUPLER:

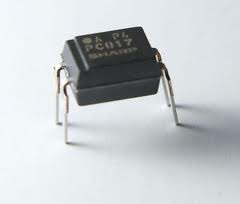
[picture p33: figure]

Opto-Coupler IC

The PC-817 contains a light emitting diode optically coupled to a phototransistor. It is packaged in a 4-pin DIP package and available in wide-lead spacing option and lead bend SMD option. Input-output isolation voltage is 5000 Vrms. Response time, tr, is typically 4 µs and minimum CTR is 50% at input current of 5 mA.

`

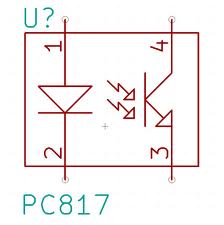
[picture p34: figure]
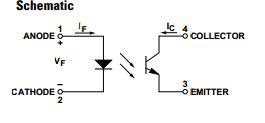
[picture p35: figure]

Internal connection and schematic of Opto-Coupler IC PC817

## DC-12V RELAY:


Relay

A relay is an electrical switch that uses an electromagnet to move the switch from the off to on position instead of a person moving the switch. It takes a relatively small amount of power to turn on a relay but the relay can control something that draws much more power.

## OPERATION OF RELAY:

Relays (and switches) come in different configurations. The most common are shown to the right. Single Pole Single Throw (SPST) is the simplest with only two contacts. Single Pole Double Throw (SPDT) has three contacts. The contacts are usually labelled Common (COM), Normally Open (NO), and Normally Closed (NC). The Normally Closed contact will be connected to the Common contact when no power is applied to the coil. The Normally Open contact will be open (i.e. not connected) when no power is applied to the coil. When the coil is energized the Common is connected to the Normally Open contact and the Normally Closed contact is left floating. The Double Pole versions are the same as the Single Pole version except there are two switches that open and close together. Select a relay with contacts that can handle the voltage and current requirements of the load. Keep in mind that some loads (such as motors) draw much more current when first turned on than they do at steady state. Select a relay with a coil voltage and current that you can control easily. Ex: If you want to turn on the AC unit with a 12VDC power supply get a 12VDC coil. Note: Coils will be rated for either AC or DC.


Relay Operation

## The primary functions of a relay are:

- The galvanic separation of the primary or actuating circuit and the load circuits
- Single input/multiple output capability
- Separation of different load circuits for multi-pole relays
- Separation of AC and DC circuits
- Interface between electronic and power circuits
- Multiple switching functions, e.g. delay, signal conditioning
- Amplifier function.

## Applications of Relay:

Typical applications for relays include laboratory instruments, telecommunication systems, computer interfaces, domestic appliances, air conditioning and heating, automotive electrics, traffic control, lighting control, building control, electric power control, business machines, control of motors and solenoids, tooling machines, production and test equipment.

TARANG F4 ZIGBEE MODULE:


MELANGE TANRANG F4 ZIGBEE MODULE

ZigBee is a low-cost, low-power, wireless mesh network standard. The low cost allows the technology to be widely deployed in wireless control and monitoring applications. Low power usage allows longer life with smaller batteries. Mesh networking provides high reliability and more extensive range. ZigBee chip vendors typically sell integrated radios.

The ZigBee network layer natively supports both star and tree typical networks, and generic mesh networks. Every network must have one coordinator device, tasked with its creation, the control of its parameters and basic maintenance. Within star networks, the coordinator must be the central node. Both trees and meshes allows the use of ZigBee routers to extend communication at the network level.

## Features and Benefits:

- Point to point, point to multi point, Mesh and peer-to-peer topologies on proprietary stack.
- Direct Sequence Spread Spectrum technology.
- Each direct sequence channel has 64K unique network addresses.
- Transmit Power: 0 dBs
- RF data rate: 250 kbps.
- Acknowledgement mode communication with retries.
- Power saving modes.
- Source / destination addressing.
- Unicast and broadcast communication.
- Analog to digital conversion and digital I/O line support.
- Default configuration for ready to use.

## Specifications:

# Power

Supply Voltage | 3.3 to 3.6V
Transmit Current | 45mA
Idle/Receive Current | 50mA
Power-down Current | <10 µA

# General

Rating Frequency | ISM 2.4 - 2.4835 GHz
Maximum Transmit Power Output | 1mW (+0 dBm)
RF Data Rate | 250 kbps
Receiver Sensitivity | -92 dBm
Serial Interface Data Rate | Up to 115200 baud
Operating Temperature | -40 to 85 °C
Antenna Options | Chip Antenna, Wire Antenna
Antenna Connector | MMCX

# Network

Supported Network Topologies | Peer-to-peer, point to multipoint & Mesh
Number Of Channels | 16 direct sequence channels
Addressing Options | PAN ID, Channel and addresses

# Mechanical

Dimensions | 37mm x 26mm.
Interface Connector | 20 pin receptacles, 2.00mm pitch.

A Wireless Distributed Network (WSN) has distributed autonomous (http://en.wikipedia.org/wiki/Autonomous) sensors (http://en.wikipedia.org/wiki/Sensor) to monitor physical or environmental conditions, such as temperature, sound, pressure (http://en.wikipedia.org/wiki/Pressure), etc. and to cooperatively pass their data through the network to a main location. The WSN is built of "nodes" – from a few to several hundreds or even thousands, where each node is connected to one (or sometimes several) sensors.

ZigBee based wireless sensor networks have tremendous usage potential, because they are much more flexible in both installation and running operation mode than conventional wired networks. ZigBee wireless networks are adaptive and self-healing, that means these networks can withstand even hostile changes in the environment, like devices leaving the network due to hardware malfunctions or electromagnetic interferences. The ZigBee specification puts very much emphasis on battery power conservation all the layers (physical, Media Access Control (MAC), network and application) from the ground up (IEEE 802.15.4) support this most important goal. The standard specifies that a ZigBee End Device (ZED) must be able to operate at a minimum for 2 years on a single battery cell. [1] The transmission is low data rate, that means that while the maximum theoretical throughput between two devices can be up to around 250 kbps.

## SIM900 GSM MODULE:

You need only two wires (TX, RX) except Power supply to interface with microcontroller / Arduino. The built in Power supply allows you to connect wide range unregulated power supply. Using this modem, you can send SMS, data and read SMS through simple AT command.


SIM900 GSM MODULE

This is a complete Quad-band GSM/GPRS module in a SMT type and designed with a very powerful single-chip processor integrating AMR926EJ-S core, allowing you to benefit from small dimensions and cost-effective solutions.

Featuring an industry-standard interface, the SIM900 delivers GSM/GPRS 850/900/1800/1900MHz performance for voice, SMS, Data, and Fax in a small form factor and with low power consumption. With a tiny configuration of 24mm x 24mm x 3 mm, SIM900 can fit almost all the space requirements in your M2M applications, especially for slim and compact demands of design.

REAL TIME CLOCK:


REAL TIME CLOCK

A real-time clock (RTC) is a computer (http://en.wikipedia.org/wiki/Computer) clock (http://en.wikipedia.org/wiki/Clock) (most often in the form of an integrated circuit (http://en.wikipedia.org/wiki/Integrated_circuit)) thatkeeps track of the current time (http://en.wikipedia.org/wiki/Time). Although the term often refers to the devices in personal computers (http://en.wikipedia.org/wiki/Personal_computer), servers (http://en.wikipedia.org/wiki/Server_(computing)) and embedded systems (http://en.wikipedia.org/wiki/Embedded_system), RTCs are present in almost any electronic device which needs to keep accurate time.

RTCs often have an alternate source of power, so they can continue to keep time while the primary source of power is off or unavailable. This alternate source of power is normally a lithium battery (http://en.wikipedia.org/wiki/Lithium_battery) in older systems, but some newer systems use a supercapacitor (http://en.wikipedia.org/wiki/Supercapacitor) because they are rechargeable and can be soldered (http://en.wikipedia.org/wiki/Soldering). The alternate power source can also supply power to battery backed RAM (http://en.wikipedia.org/wiki/Nonvolatile_BIOS_memory).

Most RTCs use a crystal oscillator (http://en.wikipedia.org/wiki/Crystal_oscillator) but some use the power line frequency (http://en.wikipedia.org/wiki/Utility_frequency). In many cases the oscillator's frequency is 32.768 kHz. This is the same frequency used inquartz clocks and watches (http://en.wikipedia.org/wiki/Quartz_clock), and for the same reasons, namely that the frequency is exactly 2¹⁵ cycles per second, which is a convenient rate to use with simple binary counter circuits.

Purpose:

- Low power consumption (important when running from alternate power)
- Frees the main system for time-critical tasks
- Sometimes more accurate than other methods

USB FLASH DRIVE CONNECTIVITY:


USB FEMALE PORT USB FLASH DRIVE

A USB flash drive is a data storage device (http://en.wikipedia.org/wiki/Data_storage_device) that includes flash memory (http://en.wikipedia.org/wiki/Flash_memory) with an integrated Universal Serial Bus (http://en.wikipedia.org/wiki/Universal_Serial_Bus) (USB) interface. USB flash drives are typically removable and rewritable, and physically much smaller than an optical disc (http://en.wikipedia.org/wiki/Optical_disc). Most weigh less than 30 grams (1.1 oz). Storage capacities as large as 2 TB are planned, with steady improvements in size and price per capacity expected.[4] (http://en.wikipedia.org/wiki/USB_flash_drive) Some allow up to 100,000 write/erase cycles, depending on the exact type of memory chip used, and a 10-year shelf storage time (http://en.wikipedia.org/wiki/Digital_permanence). They are smaller, faster, have thousands of times more capacity, and are more durable and reliable because they have nomoving parts (http://en.wikipedia.org/wiki/Moving_parts). Additionally, they are immune to magnetic interference (unlike floppy disks), and unharmed by surface scratches (unlike CDs). USB flash drives use the USB mass storage (http://en.wikipedia.org/wiki/USB_mass_storage_device_class) standard, supported natively by modern operating systems (http://en.wikipedia.org/wiki/Operating_system) such as Linux (http://en.wikipedia.org/wiki/Linux), OS X (http://en.wikipedia.org/wiki/OS_X), Windows (http://en.wikipedia.org/wiki/Microsoft_Windows), and other Unix-like (http://en.wikipedia.org/wiki/Unix-like) systems, as well as many BIOS (http://en.wikipedia.org/wiki/BIOS) boot ROMs. USB drives with USB 2.0 support can store more data and transfer faster than much larger optical disc drives (http://en.wikipedia.org/wiki/Optical_disc_drive).

A flash drive consists of a small printed circuit board (http://en.wikipedia.org/wiki/Printed_circuit_board) carrying the circuit elements and a USB connector, insulated electrically and protected inside a plastic, metal, or rubberized case which can be carried in a pocket or on a key chain, for example. The USB connector may be protected by a removable cap or by retracting into the body of the drive, although it is not likely to be damaged if unprotected. Most flash drives use a standard type-A USB connection (http://en.wikipedia.org/wiki/Universal_Serial_Bus) allowing connection with a port on a personal computer, but drives for other interfaces (http://en.wikipedia.org/wiki/USB_flash_drive) also exist. USB flash drives draw power from the computer via the USB connection.

Essential Components in an USB:

- Standard-A USB plug – provides a physical interface to the host computer.
- USB mass storage controller – a small microcontroller (http://en.wikipedia.org/wiki/Microcontroller) with a small amount of on-chip ROM (http://en.wikipedia.org/wiki/Read-only_memory) and RAM (http://en.wikipedia.org/wiki/Random_Access_Memory).
- NAND flash (http://en.wikipedia.org/wiki/NAND_flash) memory chip(s) – stores data (NAND flash is typically also used in digital cameras (http://en.wikipedia.org/wiki/Digital_camera)).
- Crystal oscillator (http://en.wikipedia.org/wiki/Crystal_oscillator) – produces the device's main 12 MHz clock signal (http://en.wikipedia.org/wiki/Clock_signal) and controls the device's data output through a phase-locked loop (http://en.wikipedia.org/wiki/Phase-locked_loop).
- Cover - typically made of plastic or metal - to protect the electronics against mechanical stress and even possible short circuits

SOLAR ENERGY HARVESTING:


SOLAR PANEL

Solar energy, radiant light (http://en.wikipedia.org/wiki/Light) and heat (http://en.wikipedia.org/wiki/Heat) from the sun (http://en.wikipedia.org/wiki/Sun), is harnessed using a range of ever-evolvingtechnologies such as solar heating (http://en.wikipedia.org/wiki/Solar_heating), solar photovoltaics (http://en.wikipedia.org/wiki/Solar_photovoltaics), solar thermal electricity (http://en.wikipedia.org/wiki/Solar_thermal_electricity), solar architecture (http://en.wikipedia.org/wiki/Solar_architecture) and artificial photosynthesis (http://en.wikipedia.org/wiki/Artificial_photosynthesis).

Solar technologies are broadly characterized as either passive solar (http://en.wikipedia.org/wiki/Passive_solar) or active solar (http://en.wikipedia.org/wiki/Active_solar) depending on the way they capture, convert and distribute solar energy. Active solar techniques include the use of photovoltaic panels and solar thermal (http://en.wikipedia.org/wiki/Solar_thermal_energy) collectors to harness the energy. Passive solar techniques include orienting a building to the Sun, selecting materials with favorablethermal mass (http://en.wikipedia.org/wiki/Thermal_mass) or light dispersing properties, and designing spaces that naturally circulate air (http://en.wikipedia.org/wiki/Ventilation_(architecture)).

The Earth receives 174 petawatts (http://en.wikipedia.org/wiki/Orders_of_magnitude_(power)) (PW) of incoming solar radiation (insolation (http://en.wikipedia.org/wiki/Insolation)) at the upper atmosphere (http://en.wikipedia.org/wiki/Earth%27s_atmosphere). Approximately 30% is reflected back to space while the rest is absorbed by clouds, oceans and land masses. The spectrum (http://en.wikipedia.org/wiki/Electromagnetic_spectrum) of solar light at the Earth's surface is mostly spread across the visible (http://en.wikipedia.org/wiki/Visible_light) and near-infrared (http://en.wikipedia.org/wiki/Near-infrared) ranges with a small part in the near-ultraviolet (http://en.wikipedia.org/wiki/Near-ultraviolet). Solar energy can be harnessed at different levels around the world, mostly depending on distance from the equator.

Yearly Solar fluxes & Human Energy Consumption
Solar | 3,850,000 EJ (http://en.wikipedia.org/wiki/Joule)[8] (http://en.wikipedia.org/wiki/Solar_energy)
Wind | 2,250 EJ[9] (http://en.wikipedia.org/wiki/Solar_energy)
Biomass potential | 100–300 EJ[10] (http://en.wikipedia.org/wiki/Solar_energy)
Primary energy use (2010) | 539 EJ[11] (http://en.wikipedia.org/wiki/Solar_energy)
Electricity (2010) | 66.5 EJ[12] (http://en.wikipedia.org/wiki/Solar_energy)

The project employs the benefits of solar energy harvesting once the input supply specifications are finalized. Using solar energy optimizes the circuit functions further more since the input supply power is minized as far as possible. Also this brings a certain value to the project.

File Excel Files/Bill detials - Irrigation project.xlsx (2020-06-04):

Irrigation Project - Bill details
Sl No | Particulars | Qt | Amount | date | Bill details | Total bill
1 | Parallel port to JTAG(NXG) | 1 | 250 | 2012-05-11 | OM Electronics center invoice no:8098 | 1239.63
2 | solar panel (9v/450mA) | 1 | 475
3 | TSOP (IR sensor) | 1 | 150
4 | solar charger | 1 | 300
5 | screw drive set | 1 | 118 | 2012-05-11 | Tejara tools & hardware invoice no:1751 | 125
6 | 9v envic rechargeable battery | 1 | 300 | 2012-06-11 | C.A.electronics invoice NO: 45819 | 824
7 | envic charger | 1 | 300
8 | 4+1 spike box | 1 | 120
9 | ARM7 (203)board | 1 | 1200 | 2012-04-10 | NSK electronics invoice NO:21356 | 4557
10 | 16*2 LCD | 1 | 130
11 | PT 100 | 1 | 200
12 | LDR | 1 | 5
13 | POT | 25 | 2
14 | Buge wire | 1 | 50
15 | USB to UART | 2 | 300
16 | GSM modem (SIM 300) | 1 | 2000
17 | Humidity sensor | 2 | 400
18 | Resistor set | 1 | 32
19 | Solonide valve | 1 | 350 | 2012-05-07 | NSK electronics invoice NO:1762 | 1520
20 | multimeter | 1 | 130
21 | Soil Moisture sensor | 1 | 800
22 | Relay | 1 | 10
23 | LRD | 1 | 5
24 | Wires | 1 | 25
25 | LM 35 | 1 | 35
26 | I-Relay board | 1 | 40
27 | Regent battery | 1 | 450 | 2012-08-11 | Swastik electronics invoice NO:8965 | 561
28 | Audio jack | 3 | 10
29 | Audio adoptor | 1 | 10
30 | 60 sec audio playback | 1 | 700 | 2012-08-11 | OM Electronics center invoice no:8125 | 1749
31 | VK-70 (IR sensor) | 1 | 60
32 | RFID model | 1 | 550
33 | 4 channel relay | 1 | 100
34 | 555 timer | 5 | 25
35 | 6*4 GP-PCB board | 3 | 90
36 | Switches | 10 | 116
37 | Single std wires | 1 | 17
38 | Aurdoino Uno (400115988) | 1 | 1200 | 2012-06-12 | OM technology center invoice NO:8355 | 1503
39 | LED's | 1 | 10
40 | Bread board | 1 | 60
41 | Battery circuit | 1 | 15
42 | USB cable | 1 | 25
43 | adopter | 1 | 75
44 | wires | 1 | 40
45 | 12v -1.2mA battery | 1 | 220 | 27/11/12 | NSK electronics invoice NO:2318 | 579
46 | DC-jack (power) | 5 | 40
47 | USB cable (micro) | 2 | 50
48 | Wire cutter | 1 | 75
49 | multimeter | 1 | 120
50 | multimeter probe | 1 | 25
51 | USB to mini cable | 1 | 80 | 2012-12-12 | Swastik electronics invoice NO:9659 total bill:348.15/- | 348
52 | 4 GB sd card | 1 | 250
53 | 12v-o-12v 1A transformer | 1 | 140 | 2012-12-12 | NSK electronics invoice NO:2397 | 535
54 | TTL to MAX 232 board | 1 | 60
55 | IR sensor | 1 | 100
56 | DB9 female | 6 | 24
57 | Multiple power supply | 1 | 170
58 | 6v ,1.3AH battery | 1 | 300 | 26/03/13 | C.A.electronics invoice NO: 48939 | 1317
59 | 12v ,1.3AH battery | 1 | 450
60 | charger | 1 | 250
61 | AA envic R/C | 1 | 150
62 | 4 GB sd card | 1 | 250 | 2012-12-12 | Swastik electronics invoice NO:9659 | 348
63 | USB to micro | 1 | 80
64 | DB9- male to male & female to female | 2 | 100 | 16/04/13 | sri lakshmi electronics invoice NO:6186 | 100
65 | solar cell | 1 | 500 | 30/01/13 | OM technology center invoice NO:8989 | 528
66 | Plastic boxes | 5 | 60 | 19/04/13 | Rajesh plastics invoice NO:26098 | 300
67 | Bread board | 1 | 60 | 17/11/12 | OM technology center invoice NO:8210 | 143
68 | multimeter plugs | 1 | 75
69 | X-Bee base board | 1 | 1200 | 14/01/13 | OM technology center invoice NO:8761 | 2825
70 | X-Bee (s2) | 1 | 125
71 | T-wire | 1 | 25
72 | B-stick | 1 | 3
73 | PT 100 | 2 | 130 | 28/02/13 | OM technology center invoice NO:1276 | 749
74 | Humidity sensor | 1 | 450
75 | PCB boards |  | 122 |  | OM technology center invoice NO:8955 | 489
76 | 9v battery | 4 | 48
77 | IC base | 1 | 8
78 | all buzzer | 1 | 25
79 | 2 pin | 4 | 10
80 | IRLED | 5 | 60
81 | Resistor set | 4 | 20
82 | LDR | 10 | 50
83 | Sump wire | 3 | 75
84 | Header | 7 | 21
85 | F-Header | 5 | 25
86 | Gear motor | 2 | 130 | 2013-02-04 | OM technology center invoice NO:8958 | 742
87 | wheel | 4 | 35
88 | 40 pin base | 1 | 8
89 | Wire | 2 | 15
90 | lamp | 4 | 8
91 | Screws | 3 | 12
92 | F- Header | 5 | 14
93 | Header.M | 4 | 5
94 | 5v adopter | 1 | 75
95 | 9v battery | 4 | 3
96 | wheel | 1 | 42
97 | Tarqar F4 | 2 | 980 | 16/01/13 | NSK electronics invoice NO:2570 | 2384
98 | USB to other converter | 1 | 300
99 | GSM modem (SIM 300) - TTL | 1 | 900 | 2013-05-02 | NSK electronics invoice NO:3164 | 1860
100 | PT - 100 | 2 | 180
101 | SY-HS 220 | 1 | 425
102 | Holder pins(zigbee) | 4 | 20
102 | PCB boards | 2 | 28 | 2013-05-02 | Kwality Electronics, No:12944 | 101
103 | Resistor set - 20 | 1 | 0.25
104 | LDR | 1 | 35
105 | Eveready cells | 10 | 80 | 2013-03-04 | om technology center, No. 1313 | 128
106 | 9v battery | 10 | 80
107 | 4 cell holder | 2 | 24
108 | 9v battery cap | 1 | 3
109 | USB to UART | 1 | 250 | 2013-05-16 | NSK electronics, 3271 | 264
110 | Screws | 1 | 20 | 2013-05-21 | OM Technology Center, 3418 | 80
111 | Spacer | 1 | 50
112 | Hand drill | 1 | 220 | 2013-05-21 | Tijarah Tools and hardware, 3128 | 376
113 | Bits | 2 | 22
114 | Tester | 1 | 44
115 | Dual side gum tape | 1 | 70
116 | IC set (317) | 2 | 94 | 1900-07-16 | NSK Electronics, 3287 | 198
117 | 7.4v lithium battery | 2 | 550 | 2013-06-06 | C.A electronics,50643 | 1260
118 | sim 900 | 1 | 1250 | 2013-09-06 | coiNel Technology solutions | 1250
119 | Single side PCBS | 10 | 370 | 2013-06-06 | Orion Computers no:7698 | 3904
120 | Lithium Charger Universal | 1 | 1500 | 2013-06-10 | C.A Electronics No: 50738 | 1718
121 | Glue Gun | 1 | 250 | 2013-06-10 | Hatimi Electronics No: 18089 | 264
122 | Sim 300 Module TTL | 1 | 900 | 2013-06-10 | NSK Electronics No:3377 | 950
123 | Spaner | 1 | 50 | 21/05/2013 | OM Technology Center, 3418 | 80
124 | Screw | 1 | 20
125 | Glue Gun | 1 | 250 | 2013-10-06 | Hatimi Electronics No: 18089 | 264
126 | Hand Drill | 1 | 220 | 2013-04-05 | Tijarah Tools and hardware, 3128 | 376
127 | Bits | 2 | 22
128 | tape | 1 | 70
129 | terts | 1 | 44
130 | Sim 300 Module TTL | 1 | 900 | 2013-10-06 | NSK Electronics No:3377 | 950
131 | GSM Sim 300 Module TTL | 1 | 900 | 2013-02-05 | NSK Electronics No:3164 | 1860
132 | PT 100 | 2 | 180
133 | S4-Hs 220 | 1 | 425
134 | Rark 1mm | 4 | 20
135 | PCB | 2 | 56 | 2013-02-05 | Kwality Electronics No:12944 | 101
136 | Red | 20 | 5
137 | LDR | 1 | 35
138 | Cell | 8 | 10 | 2012-04-03 | OM Technology Center, 1313 | 122
139 | 9V Battery | 2 | 12
140 | Battery con | 1 | 15
141 | 9V Battery con | 1 | 3
142 | 317 PS4 | 2 | 94 | 21/05/2013 | NSK Electronics No:3287 | 198
143 | 7.14V Lithium Battery R/C | 2 | 550 | 2013-06-06 | C.A.Electronics No:50643 | 1260
144 | USB to mm | 1 | 250 | 16/05/2013 | NSK Electronics No:3271 | 264
145 | SIM900A Breakout TTL Board | 1 | 1250 | 2013-09-05 | CoiNel Technology Solutions LLP | 1318.75
146 | PCBS | 10 | 370 | 2013-06-05 | Orion Computers | 3904
148 | Lithium Charger Universal | 1 | 1500 | 2013-10-06 | C.A.Electronics No:50738 | 1717.5
149 | Miselenious (Chinees SM Sensor, 6 Box, Web site registration and design , other small materials) |  | 5000 |  |  | 5000
150 | 40x1 15mm B/S | 9 | 10 | 2013-11-11 | Electroface Connectronics | 253
151 | 40x2 B/S M | 5 | 22
152 | 40x1 B/S F | 4 | 10
153 | 8870 Board | 1 | 100 | 2013-11-11 | Vishal Electronics | 105
154 | Plastic Boxes | 3 | 65 | 2013-11-11 | Sri Ambe Stores | 205
155 | PCBs | 5 | 760 | 2013-11-11 | Orion Computers | 4009
156 | 2003 IC | 3 | 10 | 2013-09-25 | Sri Lakshmi Electronics | 159
157 | 2003 Driver board | 1 | 30
158 | 4052 Analog Mux | 2 | 10
159 | LM1117 | 4 | 10
160 | MC34063 | 2 | 15
161 | 12v Relay Board | 1 | 40 | 2013-10-23 | NSK ELECTRONICS | 728
162 | 1117 3.3 Regulator | 5 | 10
163 | 1117 5V Regulator | 5 | 10
164 | USB to Serial | 1 | 250
165 | Solanaid Valve | 1 | 300
166 | Flow Sensor | 1 | 750 | 2013-10-24 | NSK ELECTRONICS | 817
167 | Opto Coupler PC 817 | 5 | 5
168 | P.U. Tube 6mm | 5 | 30 | 2013-10-24 | S. Abbas & Co. | 343
169 | Female Connector | 2 | 75
170 | 9V/4A Adaptor | 1 | 400 | 2013-10-29 | Swastik Electronics | 458
171 | MAX232 5V Board | 2 | 125 | 2013-10-29 | CoiNel Tech | 538
172 | DC Jack | 5 | 10
173 | Switch | 5 | 10
174 | AP3003 | 2 | 80
175 | 12v battery | 1 | 300 | 2013-11-04 | Navbharat Electronics | 343
176 | DC Pin | 5 | 5 | 2013-11-04 | Swastik Electronics | 578
177 | DC Ao Ckt | 5 | 4
178 | St Pin | 5 | 10
179 | EP Pin | 5 | 5
180 | 1/2 W | 10 | 0.5
181 | St 2.5 +3.5 | 10 | 30
182 | St Do Ckt | 10 | 8
183 | SIM900 TTL | 2 | 1000 | 2013-11-04 | NSK ELECTRONICS | 3298
184 | 1 CH relay Board | 2 | 50
185 | Opto Coupler | 5 | 4
186 | Switch 3P | 10 | 4
187 | Pot 10k | 10 | 3
188 | GP Board | 30 | 6
189 | R 470R | 5 | 0.2
190 | DTMF Decoder | 2 | 100
191 | Burg Con Male | 10 | 3
192 | Burg Con Female | 10 | 4
193 | Terminal Block 2P | 10 | 4
194 | Adapter 5V/2A | 1 | 120
195 | RTC EEPROM Board | 1 | 100
196 | Burg Connector | 75 | 3
197 | Multimeter probes | 1 | 75 | 2013-11-07 | Vishal Electronics | 131
198 | Inductors | 10 | 5
199 | EIP pin to pin | 10 | 40 | 2013-11-08 | Chandan Radio Centre | 1173
200 | Adaptor 12V/2A | 1 | 225
201 | Adaptor 5V/2A | 1 | 200
202 | Adaptor 9V/2A | 1 | 200
203 | USB AFRPA | 5 | 20 | 2013-11-08 | Electroface Connectronics | 116
204 | 2PM Multiplexer | 5 | 2.5
205 | Battery 7.4V | 1 | 600 | 2013-11-08 | C.A.Electronics | 2003
206 | Battery 9.6V | 1 | 600
207 | Spike Bushes | 1 | 550 | 2013-11-08 | Hussaini | 447
208 | Brass Solenoid Valve | 1 | 390
209 | Tube for Pipe | 5 | 25 | 2013-11-08 | C.P. Trading Corporation | 132
210 | TB 128 | 10 | 4 | 2013-11-08 | NSK ELECTRONICS | 3390
211 | Female Housing | 10 | 6
212 | Slide Switches | 10 | 6
213 | Relay | 5 | 40
214 | Opto Coupler | 5 | 4
215 | 100K Resistor | 20 | 0.3
216 | 10K Pot | 10 | 7
217 | Borge Sticks | 10 | 8
218 | Batteries | 10 | 1
219 | Hall-Effect Sensor | 2 | 20
220 | Magnet | 2 | 20
221 | Lead | 1 | 70
222 | LM317 | 10 | 9
223 | Pot Terminal | 10 | 3
224 | SIM900 TTL | 2 | 1200
225 | Miselenious (TA/DA and other small materials for which there is no bill) |  | 5000 |  |  | 5000
226 | Anomation - 1 |  | 4000 | 2013-01-09 | SPV design | 4000
227 | PCB soldering | 1 | 500 | 2013-11-26 | Oswal Electronics | 573
228 | 4GB SD Card | 1 | 230 | 2014-02-04 | Ashok Electronics | 665
229 | 2GB SD Card | 2 | 400
230 | 5V 2A Adaptor | 1 | 180 | 2014-02-04 | Oswal Electronics | 206
231 | Lamination | 4 | 80 | 2013-12-23 | Oza's Enterprises | 200
232 | Lamination | 2 | 50
233 | Color Xerox | 2 | 20
234 | Domain Registration | 1 | 310.61 | 2014-02-06 | GoDaddy | 310.61
 |  |  |  |  |  | 83414.49

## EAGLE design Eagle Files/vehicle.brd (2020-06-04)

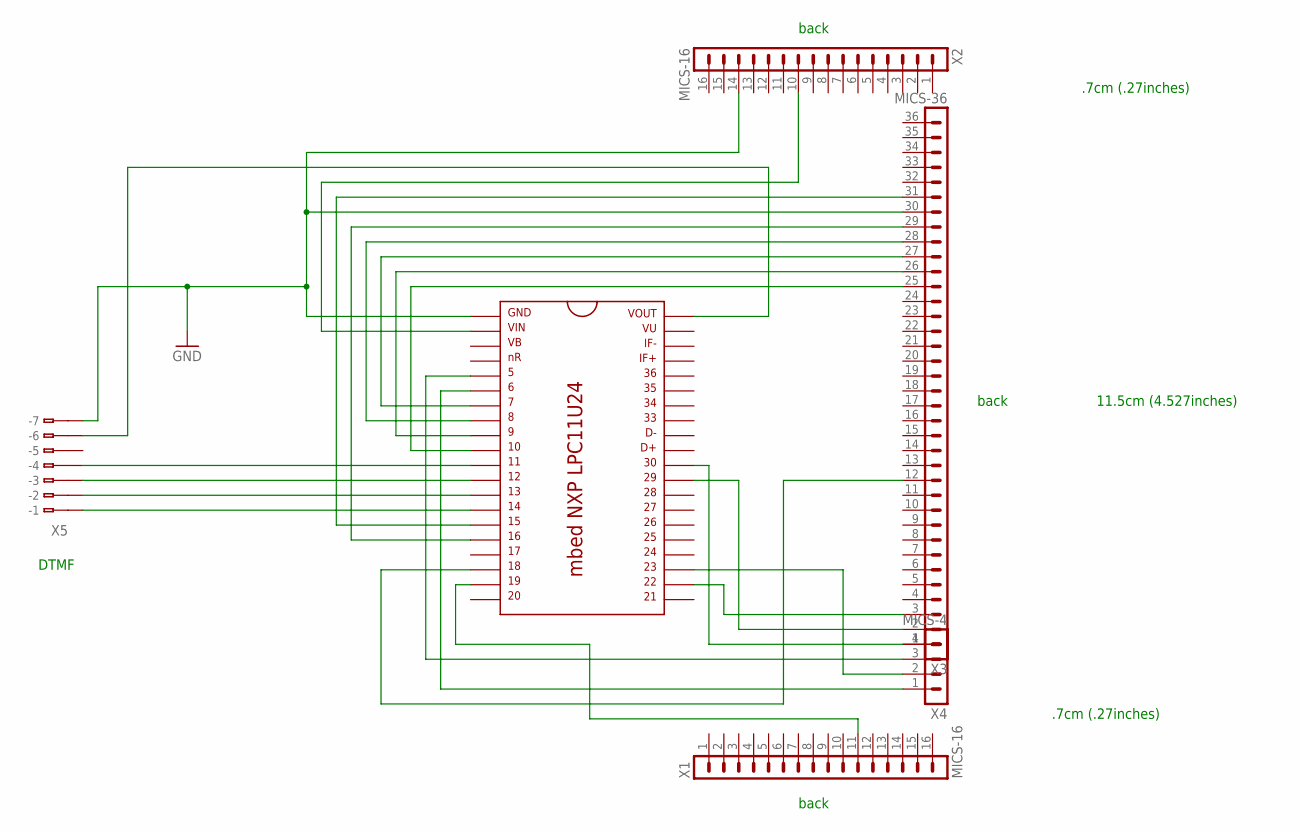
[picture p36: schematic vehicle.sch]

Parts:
IC1: MBED-NXP-LPC11U24; DIL40_0.9
X1, X2: MICS-16
X3: MICS-36
X4: MICS-4
X5: 233-107

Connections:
GND: IC1.1, X2.14, X3.30, X5.B7 (B-7)
unnamed: IC1.18, X3.12
unnamed: IC1.22, X3.3
unnamed: IC1.2, X2.10
unnamed: IC1.15, X3.31
unnamed: IC1.30, X3.1, X4.4
unnamed: IC1.16, X3.29
unnamed: IC1.8, X3.28
unnamed: IC1.7, X3.27
unnamed: IC1.9, X3.26
unnamed: IC1.10, X3.25
unnamed: IC1.29, X3.2
unnamed: IC1.5, X4.3
unnamed: IC1.23, X4.2
unnamed: IC1.6, X4.1
unnamed: IC1.19, X1.11
unnamed: IC1.40, X5.B6 (B-6)
unnamed: IC1.12, X5.B3 (B-3)
unnamed: IC1.13, X5.B2 (B-2)
unnamed: IC1.14, X5.B1 (B-1)

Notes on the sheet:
DTMF
.7cm (.27inches)
11.5cm (4.527inches)
back

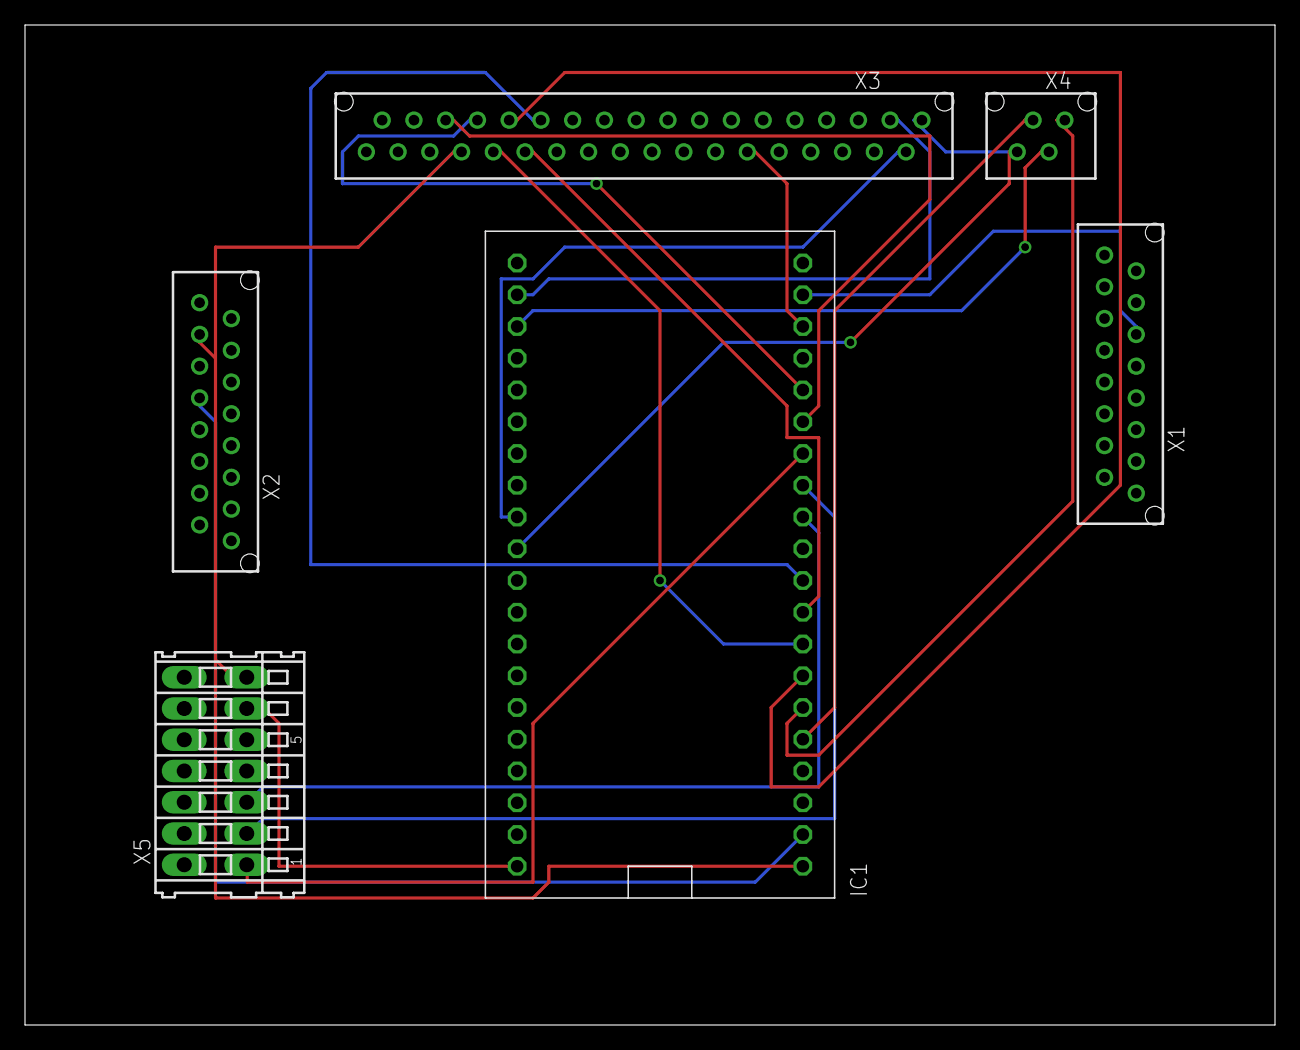
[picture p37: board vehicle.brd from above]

Board: 2 copper layers, 100.0 x 80.0 mm, 6 parts (0 on the bottom side), 20 nets.

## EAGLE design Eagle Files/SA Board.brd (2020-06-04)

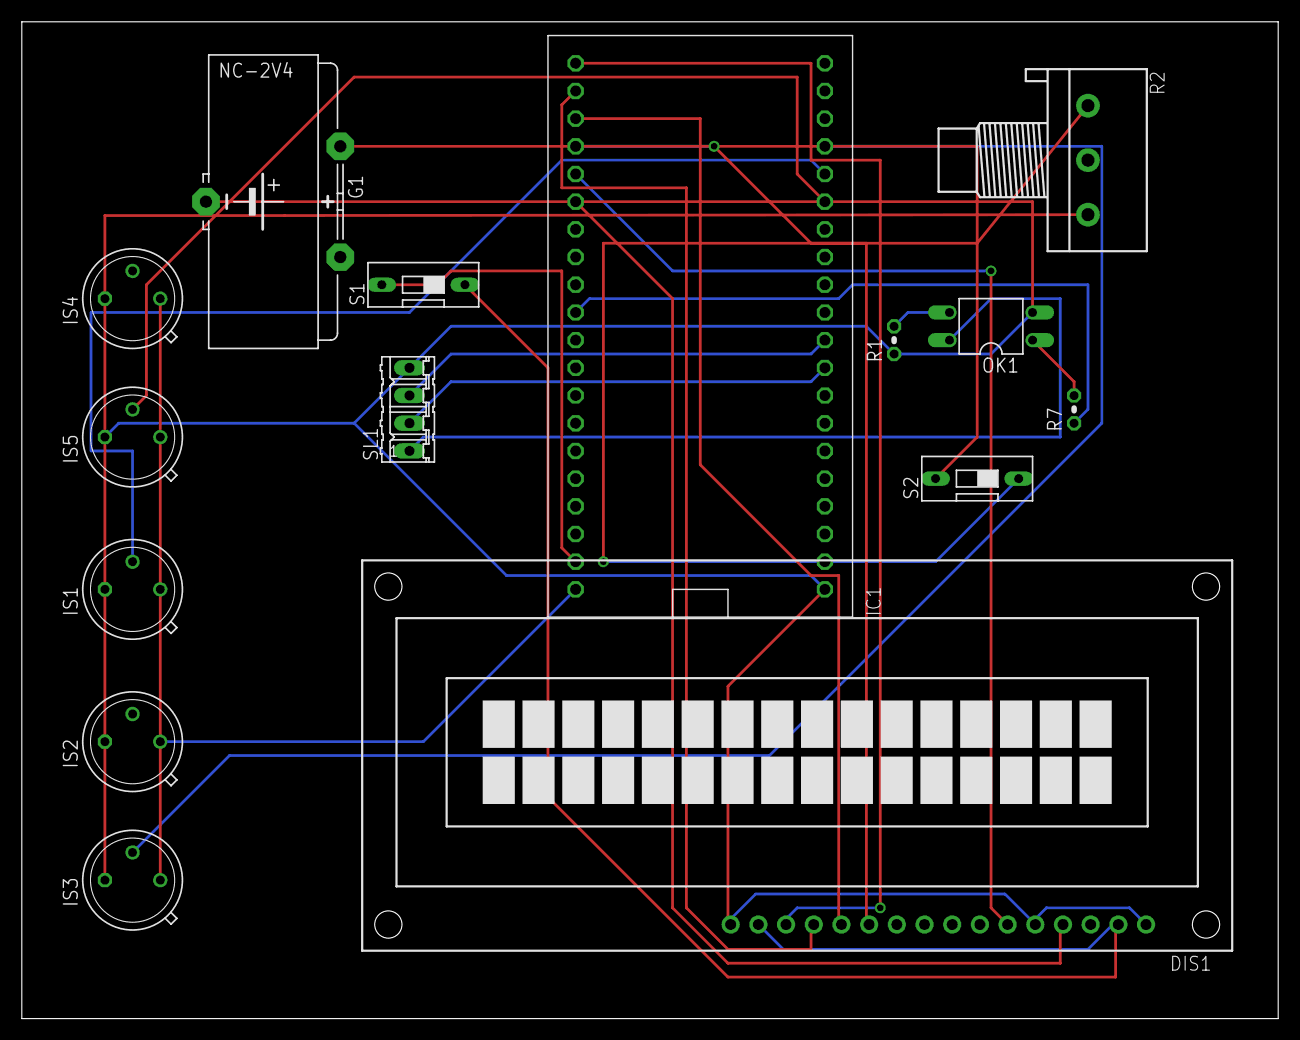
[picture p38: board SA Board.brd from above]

Board: 2 copper layers, 115.2 x 91.4 mm, 15 parts (0 on the bottom side), 21 nets.

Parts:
DIS1: TUXGR_16X2_R2
G1: 2V110R
IC1: MBED-NXP-LPC11U24; DIL40_0.9
IS1, IS2, IS3, IS4, IS5: LME-346-F; TO39
OK1: PC817; DIL04
R1, R7: 0204V
R2: 3RP/1610N
S1, S2: DS-01
SL1: 04P

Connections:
5V: DIS1.2, DIS1.15, S1.1
+5V: OK1.4, SL1.1
GND: DIS1.1, DIS1.5, DIS1.16, G1.-, IC1.1, IS1.3, IS2.3, IS3.3, IS4.3, IS5.3, OK1.2, R1.1, R2.3, SL1.4
unnamed: OK1.3, R1.2
unnamed: IC1.15, IS5.2
unnamed: IC1.39, S1.2
unnamed: DIS1.14, IC1.21
unnamed: DIS1.13, IC1.22
unnamed: DIS1.12, IC1.23
unnamed: DIS1.11, IC1.24
unnamed: DIS1.6, IC1.25
unnamed: DIS1.4, IC1.26
unnamed: IC1.9, SL1.2
unnamed: IC1.16, IS1.2
unnamed: IC1.17, IS3.2
unnamed: IC1.10, SL1.3
unnamed: IC1.40, IS1.1, IS2.1, IS3.1, IS4.1, IS5.1
unnamed: IC1.2, R2.1, S2.1
unnamed: G1.+, S2.2
unnamed: IC1.30, R7.1
unnamed: OK1.1, R7.2
